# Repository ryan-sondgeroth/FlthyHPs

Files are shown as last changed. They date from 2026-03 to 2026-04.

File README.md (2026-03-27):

# FlthyHPs (Flthy Holoprojectors)

This repo contains the `FlthyHPs_v2.1.ino` sketch and supporting documentation for controlling 3 R2 holoprojectors (Front/Rear/Top) with:

- NeoPixel LED effects (7 LEDs per projector)
- Servo articulation through an Adafruit PCA9685 I2C board
- Auto-twitch behavior for both LEDs and servos
- Serial/I2C command control (plus optional RC input)

This README is based on the manual in [`docs/Guide to Using Your FlthyHPs v1.8 .docx`](docs/Guide%20to%20Using%20Your%20FlthyHPs%20v1.8%20.docx), with updates aligned to the current `v2.1` sketch.

## At a Glance

- **Sketch:** `FlthyHPs_v2.1.ino`
- **Arduino I2C address:** `0x19` (decimal 25)
- **PCA9685 I2C address:** `0x40` (default)
- **Serial baud:** `9600`
- **HP count:** 3 (Front, Rear, Top)

## Hardware

## PCB Renders

| Top | Isometric Front |
|-----|---|
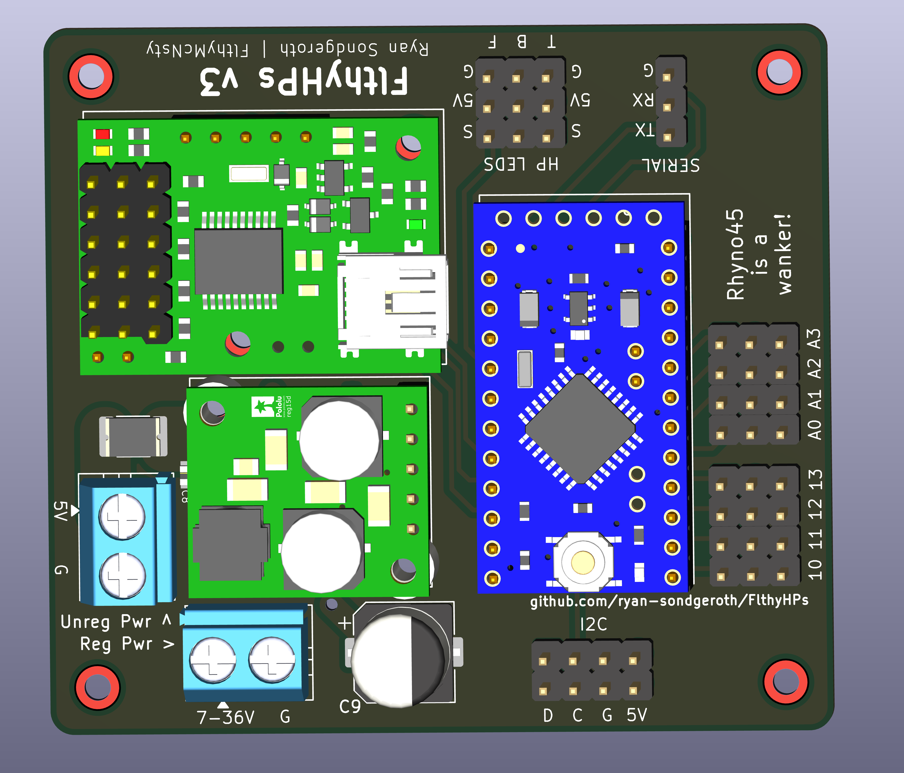
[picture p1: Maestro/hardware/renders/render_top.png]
Top view
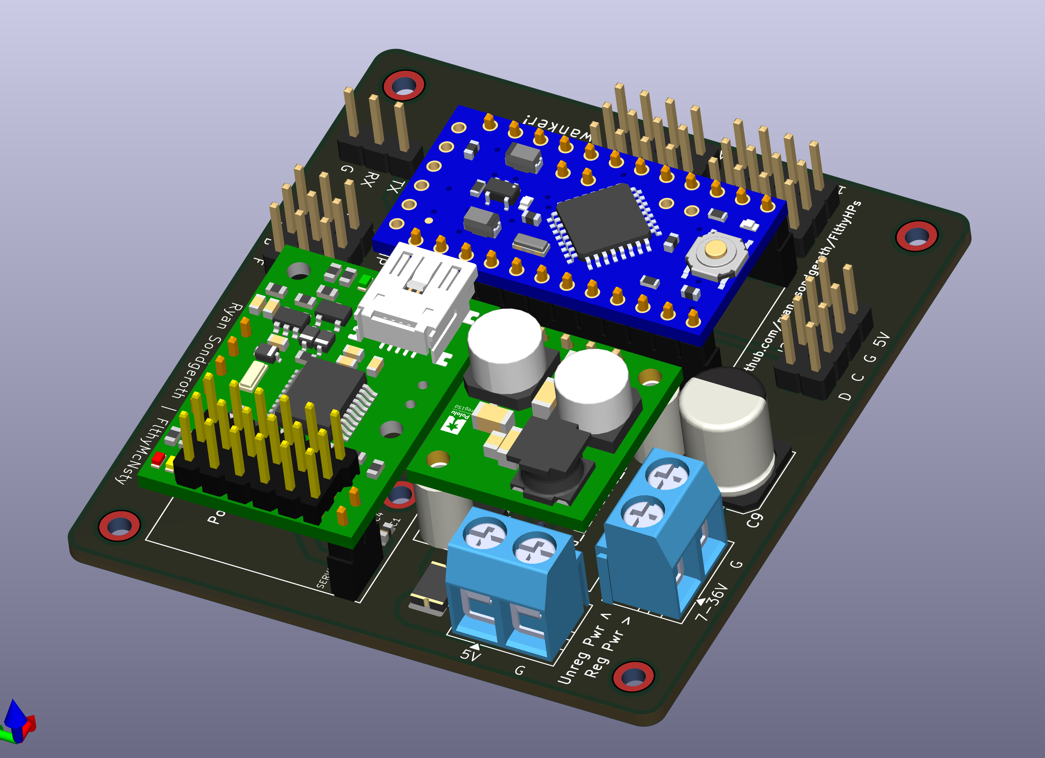
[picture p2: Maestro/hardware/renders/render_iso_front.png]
Isometric front
|  |  |

| Isometric Back | Side |
|---|---|
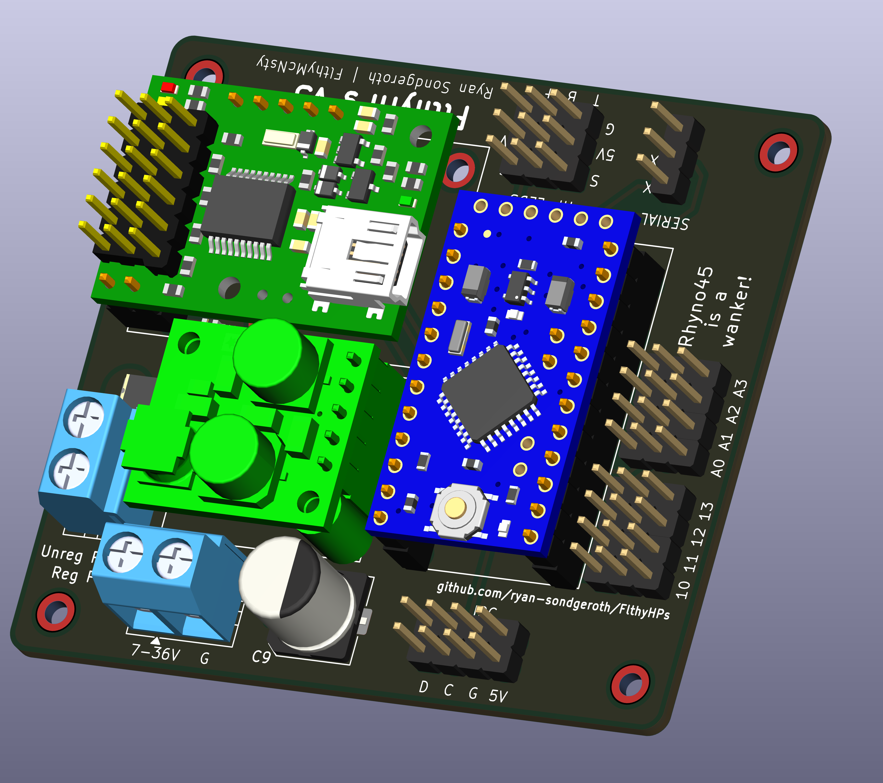
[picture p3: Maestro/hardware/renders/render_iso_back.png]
Isometric back
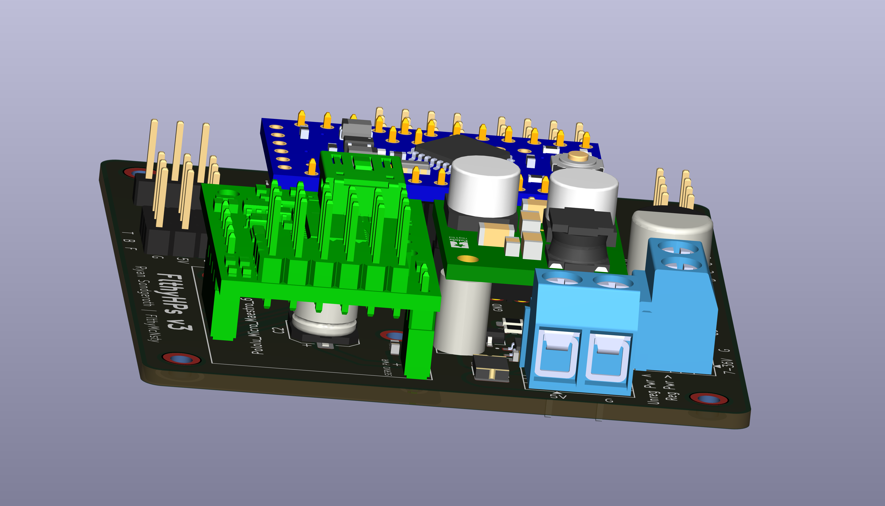
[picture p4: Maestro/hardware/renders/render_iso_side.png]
Side view
|  |  |

---

### FlthyHPs Maestro v3 PCB (current)

The v3 system replaces the separate breakout board + PCA9685 combo with a single custom PCB: **FilthyHPs_Maestro**.

- **Arduino Pro Mini** (5V, 16MHz) — plugs into U1 headers
- **Pololu Micro Maestro 6-Channel** servo controller — plugs into U2 headers (replaces PCA9685)
- **Pololu D24V50F5** 5V 5A regulator — plugs into U3 headers
- 6 servos (2 per HP) via Maestro channels 0–5
- 3 HP NeoPixel assemblies (7 LED Jewel each) via Arduino D2/D3/D4
- I2C headers (J6, J7) for external peripherals and accepting commands from I2C controllers
- Serial header (J2) for sending commands to the Arduino sketch

**Power input:**
- 7–36V unregulated via J1 screw terminal (regulated on-board by D24V50F5)
- Or regulated 5V direct via J8 screw terminal (bypasses regulator)

**Improved circuit protection over previous versions:**
- P-ch MOSFET (Q1) ideal diode gates VIN_RAW to the servo rail, preventing backfeed
- 5.1V Zener clamps (D1, D2) protect Maestro and Arduino signal lines from overvoltage
- 500mA PTC resettable fuse (F1) on the 5V logic rail — self-resetting, no fuse to replace

**Improved power stability over previous versions:**
- Bulk capacitance across the input, servo, and logic rails absorbs current spikes and smooths supply transients
- Decoupling capacitors at key IC supply pins suppress high-frequency noise

**Simplified servo setup over previous versions:**
- Moving to the Pololu Micro Maestro eliminates the tedious per-servo position configuration previously done in the sketch
- Servo travel limits, speeds, and positions are configured visually using the Maestro Control Center application, with no sketch changes required

Servo control and calibration: [`Maestro/Maestro_Setup_Guide.md`](Maestro/Maestro_Setup_Guide.md)

### Legacy hardware (v1/v2/v2.1)

Earlier versions used a Flthy breakout board + Adafruit PCA9685 servo driver. The v2.1 sketch still supports this hardware. See [`docs/README.md`](docs/README.md) for the full legacy wiring guide.

## Wiring (Default)

### Arduino pins (v3 Maestro PCB)

- `D2` Front HP LED data
- `D3` Rear HP LED data
- `D4` Top HP LED data
- `D9` RC input (optional, if enabled)
- `D10` Maestro `RST` (servo output enable control)
- `D13` status LED
- `A4/A5` I2C SDA/SCL (to J6/J7 I2C headers)
- `TX/RX` Serial to Maestro (via J2 Serial header)

### Maestro channels (v3)

- `0/1` Front HP servos
- `2/3` Rear HP servos
- `4/5` Top HP servos

### Legacy PCA9685 channels (v1/v2/v2.1)

- `0/1` Front HP servos
- `2/3` Rear HP servos
- `4/5` Top HP servos

## Required Libraries

- `Wire` (built-in)
- [Adafruit NeoPixel](https://github.com/adafruit/Adafruit_NeoPixel)
- [Adafruit PWM Servo Driver Library](https://github.com/adafruit/Adafruit-PWM-Servo-Driver-Library)
- Big Happy Dude Slow Servo library (`Servos.h`) vendored in this repo at `libraries/SlowServoPCA9685`

Note: the standard Arduino Servo library is not used due to NeoPixel timing conflicts.

### Vendored slow-servo library

This repo includes `libraries/SlowServoPCA9685` so the required `Servos.h` dependency is versioned with the sketch.

- Source in this repo: `libraries/SlowServoPCA9685`
- License in upstream headers: GNU GPL v3 or later
- Original copyright: Graham Short (2013)

## Setup and Flashing

1. Install Arduino IDE.
2. Install required libraries.
3. Install Adafruit libraries directly from upstream repos:

```bash
./scripts/install-adafruit-libs.sh
```

4. Install vendored slow-servo library from this repo:

```bash
./scripts/install-libs.sh
```

Optional: set `ARDUINO_LIB_DIR` if your Arduino libraries path is not `~/Documents/Arduino/libraries`.

5. Open `FlthyHPs_v2.1.ino`.
6. Set board to **Arduino Pro or Pro Mini** and select your FTDI serial port.
7. Adjust configuration values (if needed).
8. Upload and verify boot behavior.

## Key Sketch Settings

Common settings called out in the manual and present in the current sketch:

- `Config::I2C_ADDRESS` (`0x19`)
- `Config::SERVO_I2C_ADDRESS` (`0x40`)
- `OUTPUT_ENABLED_PIN` (`10`)
- `BRIGHTNESS` (`150`)
- `ENABLEBASICHP` (basic vs 9-point preset coordinate mode)
- `enableTwitchLED[]` and `enableTwitchHP[]`
- `LEDTwitchInterval[][]` and `HPTwitchInterval[][]`
- `SERVO_SPEED[]`
- `Config::ENABLE_SERVO_EASING` and easing duration/update interval (v2.1)

For RC control, enable the RC option in the sketch and confirm RC pulse range values match your radio.

## Command Model

Command format:

- `DT##`
- `DT##C`
- `DT##CS`
- `DT##P`
- Optional runtime suffix: `|seconds`

Where:

- `D` = device designator: `F`, `R`, `T`, `A`, `X`, `Y`, `Z`, or `S` (special sequence set)
- `T` = type: `0` LED, `1` servo
- `##` = 2-digit sequence ID
- `C` = color (0-9)
- `S` = speed (dim pulse speed 0-9)
- `P` = position (0-8 preset)

### Color values

- `0` random
- `1` red
- `2` yellow
- `3` green
- `4` cyan
- `5` blue
- `6` magenta
- `7` orange
- `8` purple
- `9` white

### LED sequences (Type `0`)

- `D001` Leia
- `D002C` Color projector
- `D003CS` Dim pulse
- `D004C` Cycle
- `D005C` Solid color
- `D006` Rainbow
- `D007C` Short circuit
- `D096` Clear LEDs, disable auto LED, disable off-color
- `D0971` Clear LEDs, auto LED default, disable off-color
- `D0972` Clear LEDs, auto LED random, disable off-color
- `D098` Clear LEDs, disable auto LED, enable off-color
- `D0991` Clear LEDs, auto LED default, enable off-color
- `D0992` Clear LEDs, auto LED random, enable off-color

### Servo sequences (Type `1`)

- `D101P` Go to preset position (`0..8`)
- `D102` RC control left/right
- `D103` RC control up/down
- `D104` Random position
- `D105` Wag left/right
- `D106` Wag up/down
- `D198` Disable auto servo twitch
- `D199` Enable auto servo twitch

### Special `S` sequences

- `S1` Leia mode (front down + Leia LEDs, others disabled)
- `S4` Clear + disable auto, off-color disabled
- `S5` Clear + enable auto (default LED twitch), off-color disabled
- `S6` Clear + enable auto (random LED twitch), off-color disabled
- `S7` Clear + disable auto, off-color enabled
- `S8` Clear + enable auto (default LED twitch), off-color enabled
- `S9` Clear + enable auto (random LED twitch), off-color enabled

### Timed command examples

```text
A006|25     # Rainbow on all HPs for 25s
F001|60     # Leia on Front HP for 60s
T1012|10    # Move Top HP to preset 2 for 10s
```

## MarcDuino Integration (from manual)

The manual includes MarcDuino `v1.5/v2` usage over I2C. Core idea:

- Connect SDA/SCL/GND between MarcDuino and FlthyHPs controller.
- Send a string command to FlthyHPs address (`25` decimal by default).
- Example:

```text
&25,"A006|10\r
```

If another device already uses address `25`, change `Config::I2C_ADDRESS` in the sketch and update MarcDuino command address accordingly.

## Notes

- The manual in `docs/` is `v1.8`; this repo sketch is `v2.1`.
- If details conflict, treat `FlthyHPs_v2.1.ino` as source of truth.

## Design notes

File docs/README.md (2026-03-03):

# Guide to Using Your FlthyHPs
by Ryan Sondgeroth
flthymcnsty

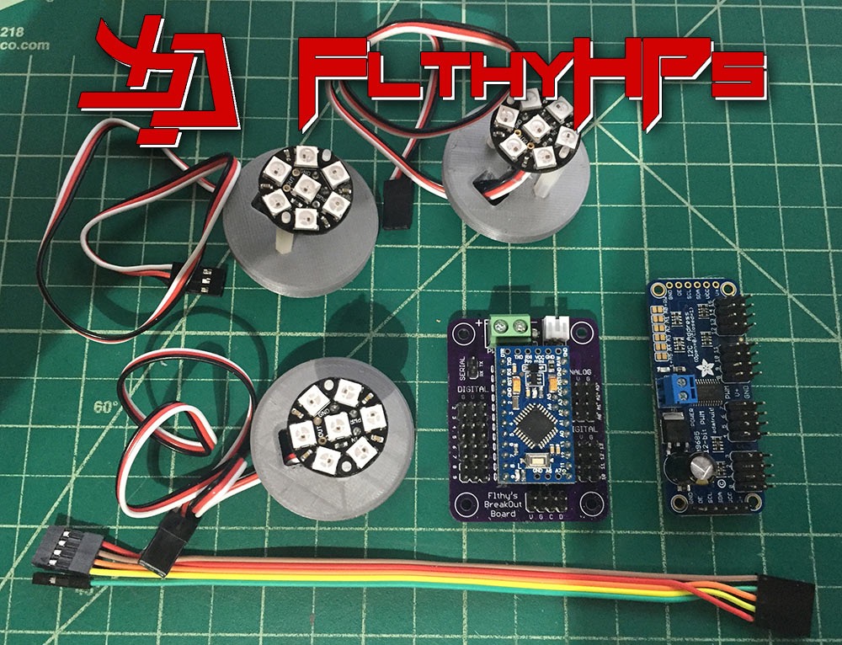
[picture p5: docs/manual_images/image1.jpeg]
Manual image 1


## Table of Contents
- What are the FlthyHPs
- What’s in the Kit
- Hooking Up Your HPs v1
- Hooking Up Your HPs v2
- Hooking Up Your HPs v2.1
- Understanding the Sketch Settings
- 1. I2C Address of the System
- 2. I2C Address of the Servo Board
- 3. HP LED Pin Assignment
- 4. Servo Board Pin Assignment
- 5. Output Enabled (OE) Pin Assignment
- 6. Enable/Disable OE
- 7. RC Enable & Input Pin Assignment
- 8. RC Pulse Width Range
- 9. Adafruit Jewel Board Version
- 10. LED Brightness
- 11. Enable/Disable LED Auto Twitch
- 12. Default LED Auto Twitch Commands
- 13. Enable/Disable Servo Auto Twitch
- 14. LED & Servo Auto Twitch Interval Ranges
- 15. Servo Speed Range
- 16. Preset HP Servo Position Coordinates
- 17. Default Color Settings
- 18. Optional Default “Off” Color
- 19. Dim Pulse Speed Range and Default Speed
- I2C/Serial Command Structure
- Special Sequence Commands
- Replacement Back Plug
- Finding Your Preset Servo Position Coordinates
- Build it Yourself
- How to Update & Flash Sketch on Arduino Pro Mini
- Using the FlthyHPs with your Marcduino v1.5/v2

## What are the FlthyHPs
What do they do and Why you want a set!
This system and sketch combines the movement and display functions of each Holoprojector into a single easy to control sketch.  Instead of using a single RGB like other HP systems, the FlthyHPs utilizes a 7 LED NeoPixel board inside each HP to produce a more life-like representation of a hologram projection.
Servo control of the system is handled by a Adafruit 16 Channel I2C Breakout board, giving increased flexibility over the I2C bus while providing significant current to safely run your HP servos.
This system also allows us to operate the HP Servos with NeoPixel LEDs from the same sketch, a problematic solutions when attempting to use the stock Arduino servo library with Adafruit’s NeoPixel library.  Big Happy Dude's Slow Servo Library is much better any way, Thanks Brad!
The system incorporates semi randomized auto twitch sequences for both the LEDs and Servos of each HP giving your droid the illusion of autonomy.   In addition to these free running auto modes,  the LED and Servo behavior can be controlled in unison or separately through a variety of sequences triggered via I2C and Serial  communication protocols.   To simplify control,  the FlthyHP system allows you to control HP functionality by sending all HP commands to a single device.
The most current version of this manual can be found at:
<http://2gwd.com/FlthyHPs/Manual/>
Rhyno45 is a Wanker, in case Ya'll didn't know!

## What’s in the Kit
Below is a picture of the complete contents of your HP kit.  Please make sure everything is included before you begin. A brief description of each part/assembly is included below.
Each system comes pretested and pre-installed with the current sketch and default settings.

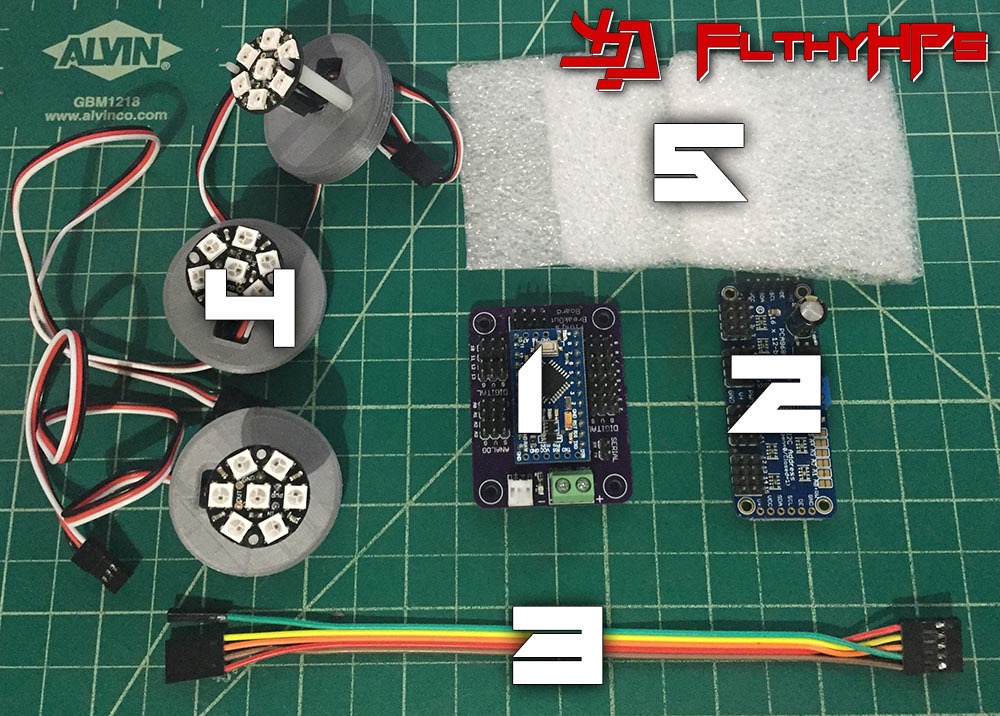
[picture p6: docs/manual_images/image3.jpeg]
Manual image 2


### 1. Arduino Pro Mini (5v 16MHz) on a Flthy Breakout Board.
The Flthy Breakout Board is a custom designed PCB* which conveniently breaks out the digital and analog pins of the Arduino Pro Mini into easy-to-use connections.   It also breaks out the Serial Tx/Rx and I2C Clock/Data pins.
The boards include a screw terminal for connecting your 5v power.  The newer v2 & v2.1 boards also break out a header row specifically for connecting to the Servo breakout board discussed below in item 2.
There have been three versions of this board, with v2.1 incorporating slight design improvements.  Sketches work on either board version.
*The breakout board designs are based on the publicly CAD Eagle files available on letsmakerobots.com.

Original Board (v1)

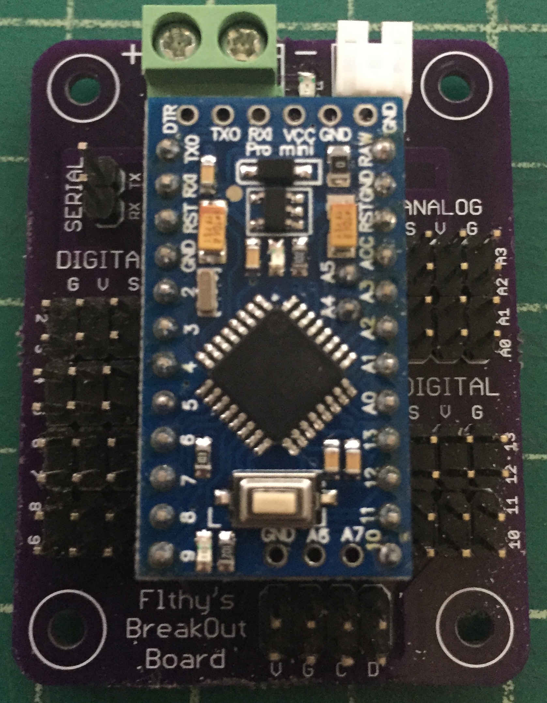
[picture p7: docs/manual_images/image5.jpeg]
Manual image 3


v2 Board 

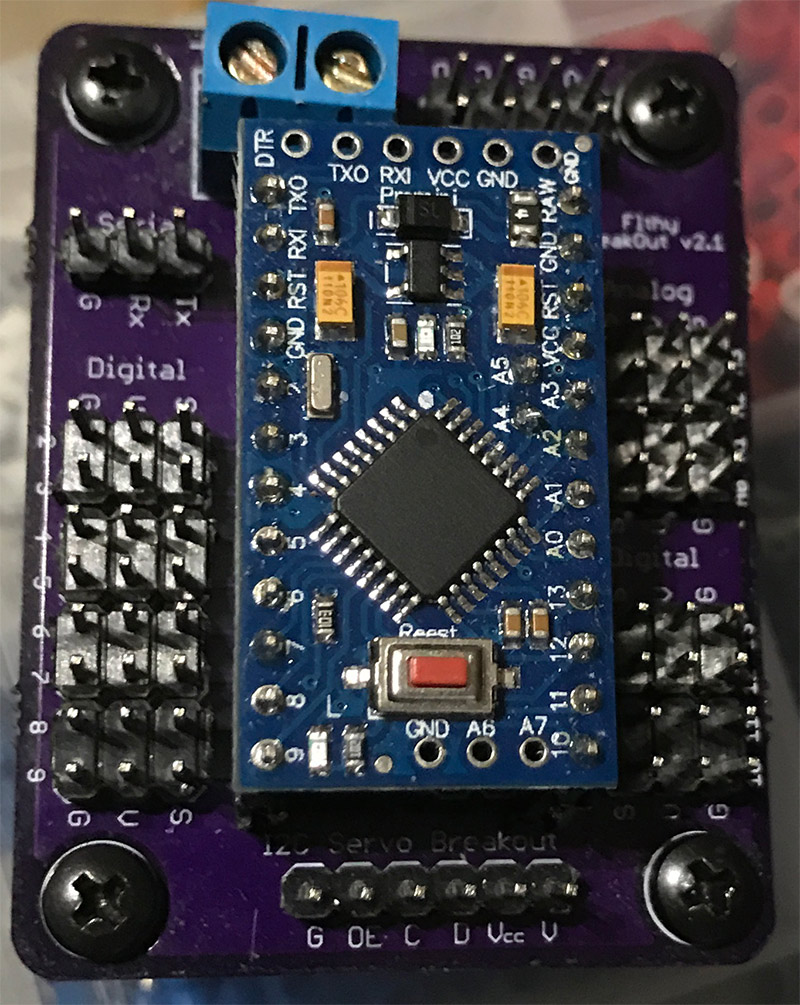
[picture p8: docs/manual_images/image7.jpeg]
Manual image 4


v2.1 Board

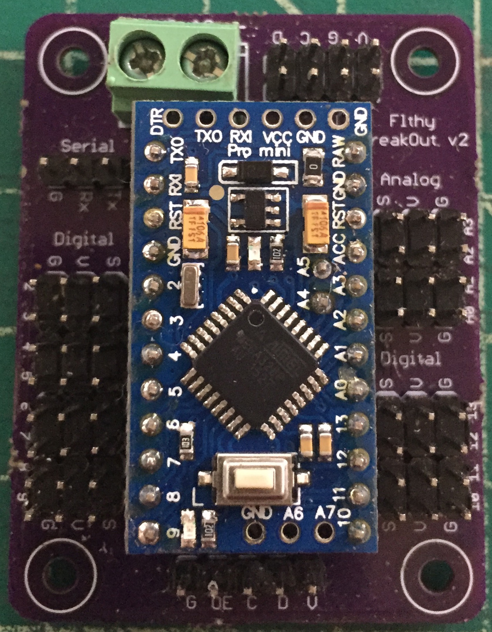
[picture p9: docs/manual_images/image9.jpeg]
Manual image 5


*The v2.1 breakout board incorporates a few design improvements making connections to it much easier.

### 2. Adafruit 16 Channel I2C Servo Breakout board*

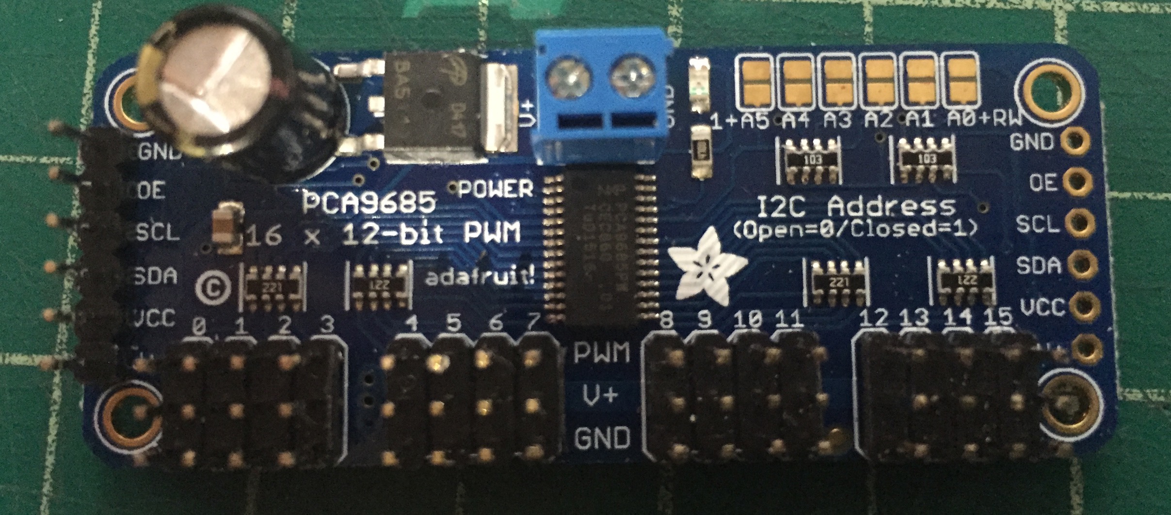
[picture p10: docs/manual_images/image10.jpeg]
Manual image 6


See product info at
<https://www.adafruit.com/product/815>
*Optional…Because some R2 Builders may not wish to articulate their HPs, some kits are available without this board.

### 3. 6 Wire Jumper Cable
For kits using the newer v2.1 Break Out Board, this is simply a basic straight 6 wire jumper cable as the header pins are broken out in the same arrangement as they appear on the Servo board including the V line.   This was done to simplify the connection process.
For kits using the v2 Break Out Board, this is simply a basic straight 5 wire jumper cable as the header pins are broken out in the same arrangement as they appear on the Servo board minus the V line.   This was done to simplify the connection process.
For kits using the v1 Breakout Board, a pre-wired jumper cable is used to connect the Servo Breakout Board to the Arduino.   It has the wires swapped correctly for proper connection.

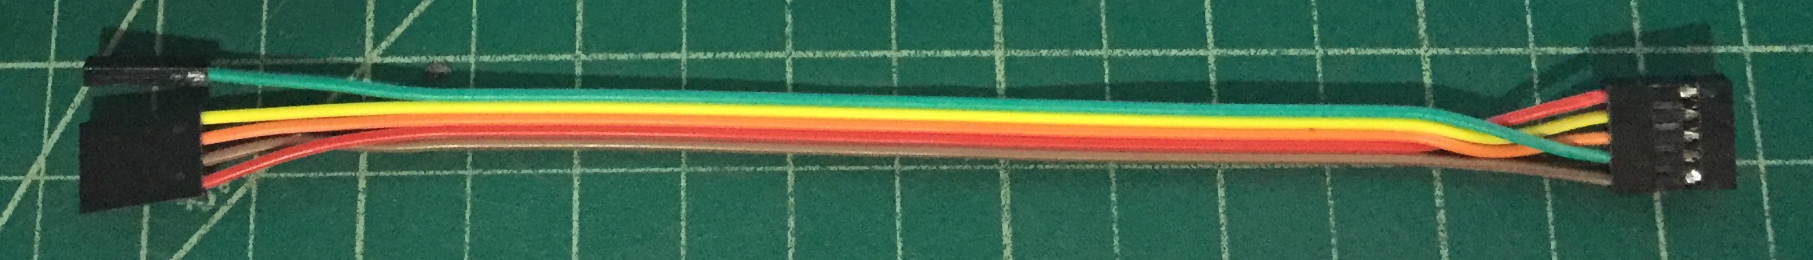
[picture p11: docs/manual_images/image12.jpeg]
Manual image 7


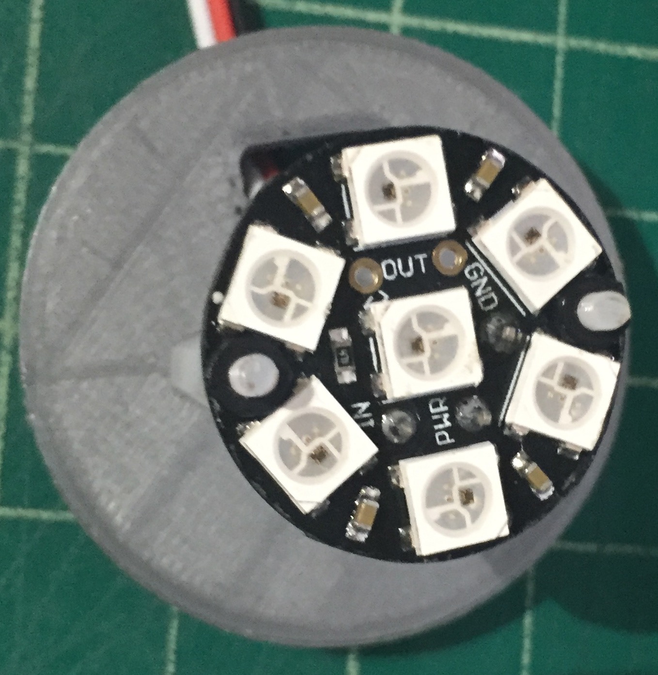
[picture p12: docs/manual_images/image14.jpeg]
Manual image 8


### 4. HP LED Assemblies (Qty. 3)
Each assembly consists of a Adafruit NeoPixel Jewel 7 LED Board (https://www.adafruit.com/products/2226), mounted on a custom 3D printed backplate via M2 nylon standoffs and connected with a 30cm 3 wire lead.
There are now 3D printed back plates available for the recent Pwrsrce (1 5/8”-20 threads) aluminum halo-projector run as well as those for the BobC HPs (1 5/8”-24 threads).
The center hole comes tapped for an M4 patterned bolt.

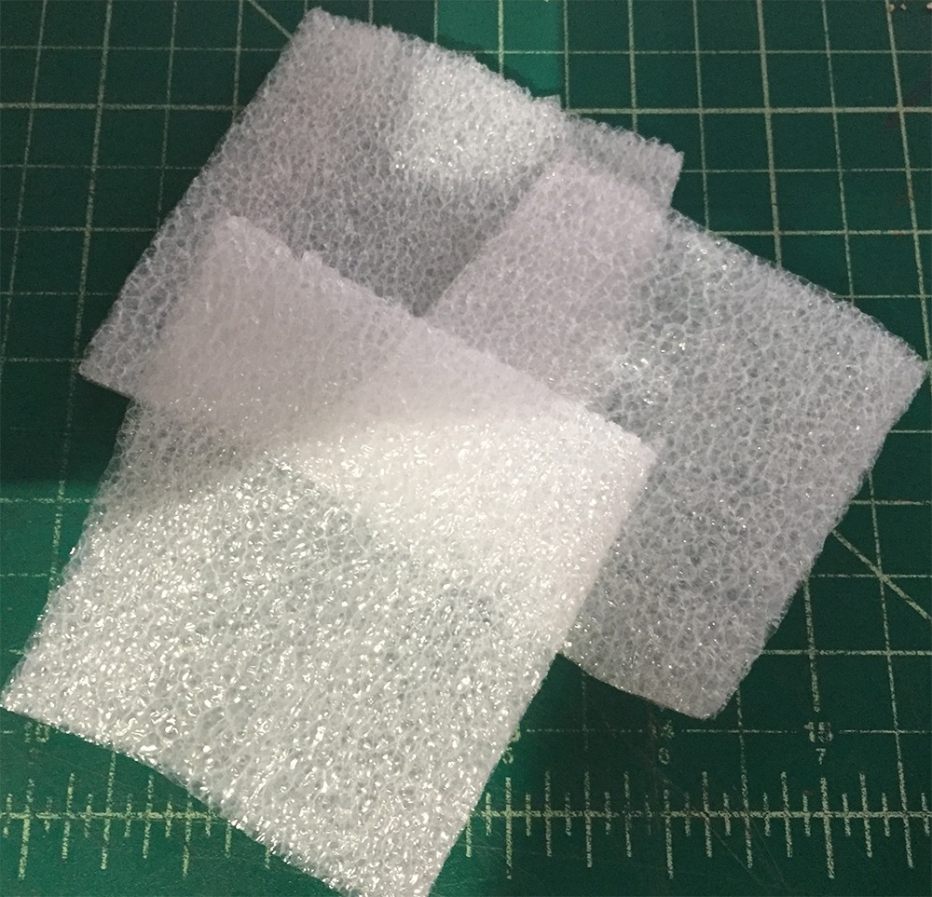
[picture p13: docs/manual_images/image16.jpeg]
Manual image 9


### 5. 1/4" Micro Foam Packaging Wrap (Qty. 3)
These 3 pieces can serve as a light diffuser between the HP’s LEDs and its lens, just cut to size.  They help blur the lines between the individual LEDs while maintaining a multicolor display.  The foam construction also gives the HP’s light a unique texture when looking directly into the lens. (Which I don’t recommend you do for long periods of time)

## Hooking Up Your HPs v1
What Wires Go Where?
Wiring Diagram for kits with Original v1 Breakout Boards
The wiring for this system is straight forward.  Both boards take 5v with the servos and LEDs attached as shown.

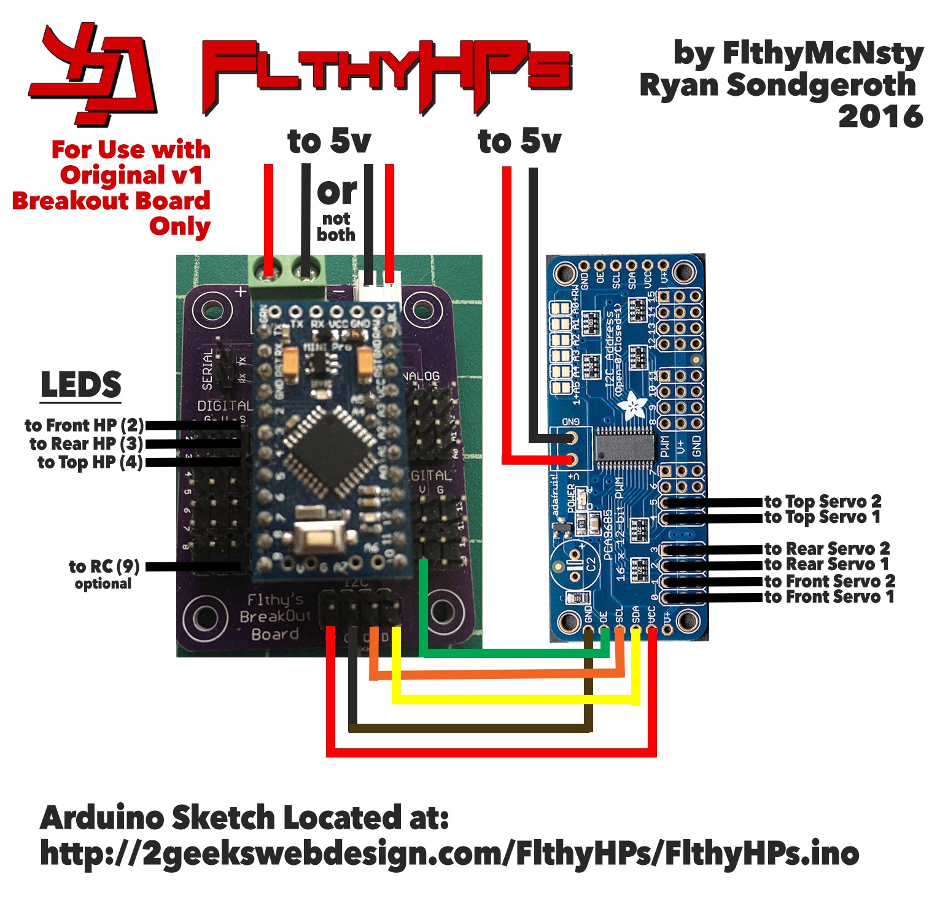
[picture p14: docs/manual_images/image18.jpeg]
Manual image 10


Attention for Kits Using the Original v1 Breakout Board!
Pay special attention to the wiring between the v1 Arduino breakout board and the servo breakout board.  The servo breakout board uses a different pin layout than the standardized I2C pin layout used by other systems created by R2 Builders.  Incorrectly connecting the servo board can result in damage.  In order to help prevent this occurrence, each kit is provided with a 5 wire jumper cable (pictured below) which has been rearranged into the correct wiring pattern with each wire matching the color used in the wiring diagram above.
Custom Wire for the Original v1 Board Design

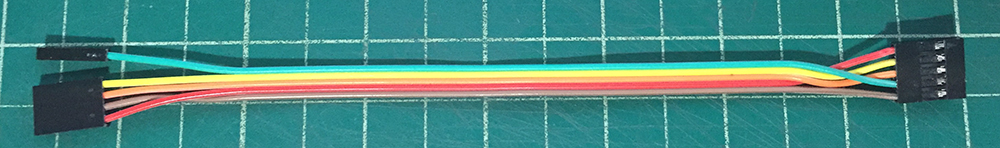
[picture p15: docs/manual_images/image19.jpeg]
Manual image 11


The v2 breakout board breaks out the pins in the same order as the servo board, simplifying the connection, and minimizing the confusing wiring.

## Hooking Up Your HPs v2
What Wires Go Where?
Wiring Diagram for kits with v2 Breakout Boards
The wiring for this system is pretty straight forward.  Both boards take 5v with the  servos and LEDs attached as shown.

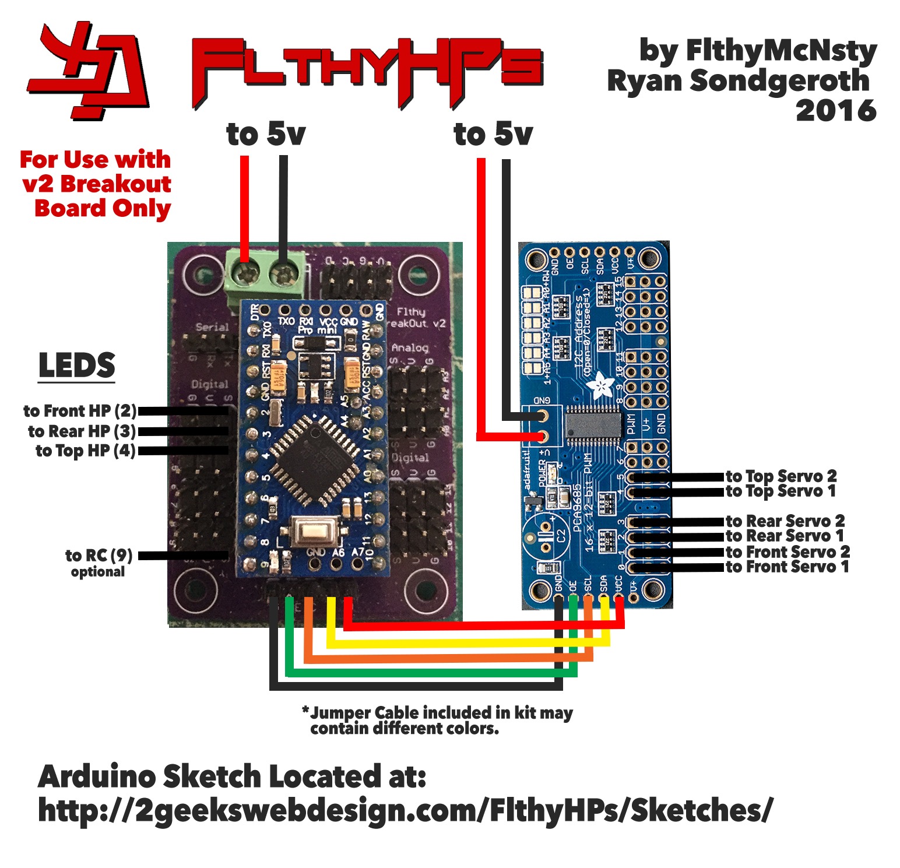
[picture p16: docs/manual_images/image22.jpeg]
Manual image 12


## Hooking Up Your HPs v2.1
What Wires Go Where?
Wiring Diagram for kits with v2.1 Breakout Boards
The wiring for this system is straight forward.  Both boards take 5v with the servos and LEDs attached as shown but the v2.1 now includes a V pin on the Servo Board Pin Out, so you do not need to provide separate power to the I2C servo breakout board.

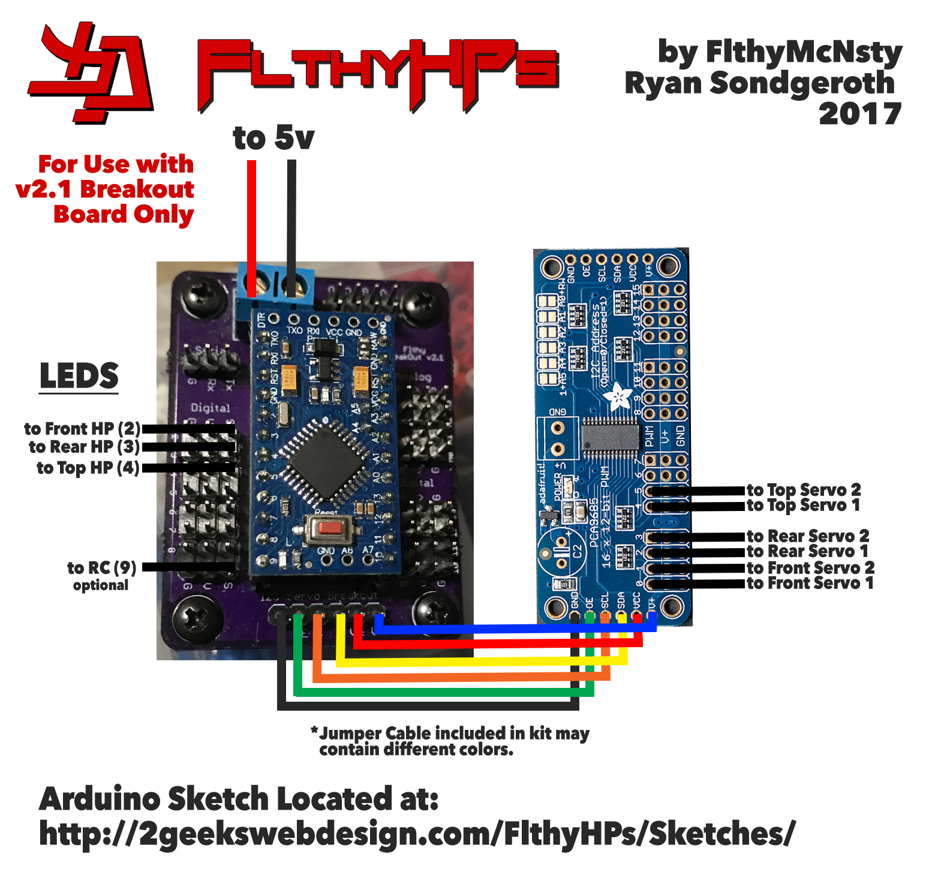
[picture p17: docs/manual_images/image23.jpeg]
Manual image 13


## Understanding the Sketch Settings
Explanation of User Definable Settings in the v2.1 Code (v1.8-compatible with v2.1 additions)
I keep the most current versions of my FlthyHP sketch freely available on my web server at: http://2gwd.com/FlthyHPs/Sketches
For those who use my sketch and feel you may have a way to improve upon it, please share your ideas and thoughts with me.   Together we can continue to improve our droids.
As you review the sketch, you will see I have broken out several settings into user definable variables in order to let each user tweak the system to their specific needs.  Below is a complete list of each of these variables with a brief explanation of its function and purpose.

### 1. I2C Address of the System
Since each device on the I2C bus can and must be assigned its own unique address, this variable allows you to do so.  An I2C address of 25 has been standardized for other HP devices so I used it as well.   It can be changed with the following variable.   Please note that it is set using the hexadecimal equivalent of the address’s decimal value.
```cpp
constexpr uint8_t I2C_ADDRESS = 0x19;  // 25 in hexadecimal
```

### 2. I2C Address of the Servo Board
Similarly, we need to set a unique I2C address for the Adafruit Servo Breakout Board.
Unlike our Arduino based control board, the Servo Breakout board is only capable of using an I2C address in the range between 64 and 126.   The specific address the board uses can be set using the set of 6 solder pads located on the top of the PCB.  By default, the board has an address of 64, and no changes are needed if you are not using the same board elsewhere on the I2C bus or have assigned another device with this address.

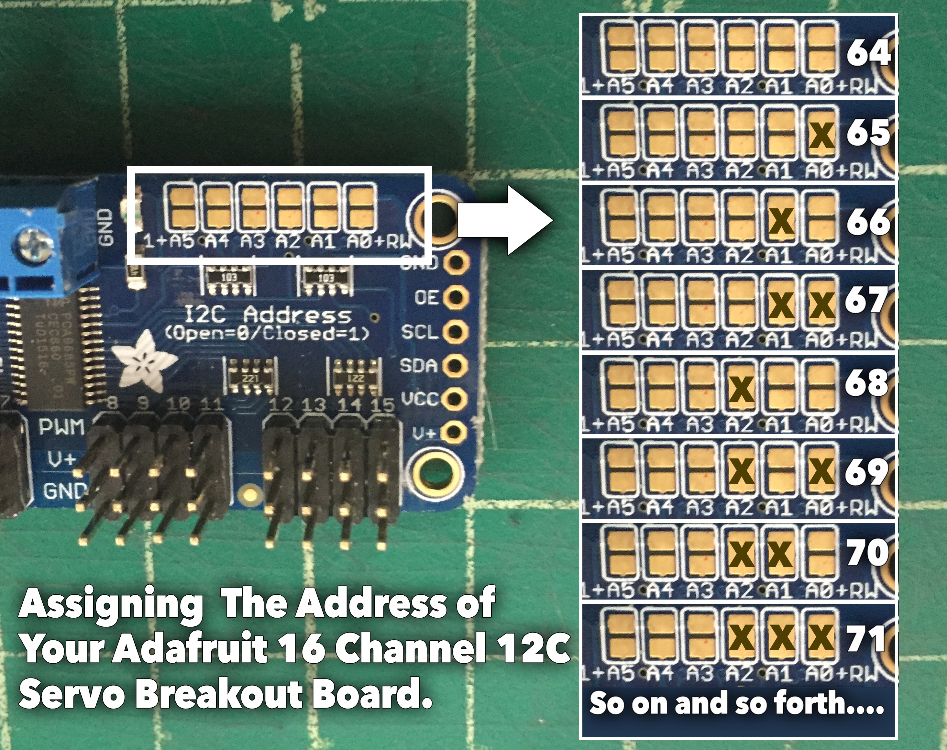
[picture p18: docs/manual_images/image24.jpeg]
Manual image 14


However, if you do need to make changes to the boards address you can do so by using the solder pads to select a new address value.  To do so, you simply place a bead of soldier across the gap in the requisite pad pairs.
The address value is determined just as you would using binary as show in this image.
Once you have set your Servo board’s address, you will then need to change this address in the Sketch.  It can be changed with the following variable.   Again, please note that it is set using the hexadecimal equivalent of the address’s decimal value.
```cpp
constexpr uint8_t SERVO_I2C_ADDRESS = 0x40;  // 64 in hexadecimal
```
If there is no need to reassign the Servo board’s address, the default value in the sketch can be left as is.

### 3. HP LED Pin Assignment
This variable allows you to set which of the Arduino’s digital pins are used to connect each of the 3 LED displays.  The first value being the front HP, the second the rear HP and the third the top HP.   Under most situations, the default values can be left unchanged.
```cpp
const uint8_t LED_PINS[Config::HP_COUNT] PROGMEM = {2, 3, 4};  // {Front, Rear, Top}
```

### 4. Servo Board Pin Assignment
This variable allows you to set which of the Servo breakout board’s pins are used to connect each of the 6 servos.  The first value pair being for the front HP, the second value pair for the rear HP and the third pair for the top HP.   Under most situations, the default values can be left unchanged.
```cpp
// Front HP Pins, Rear HP Pins, Top HP Pins
const uint8_t HP_PINS[Config::HP_COUNT][2] PROGMEM = {{0,1}, {2,3}, {4,5}};
```
Important: It is recommended that you remain consistent with how you orient your HP mounts and control system so that the two servos for each HP are positioned in a similar manner with the others.  Likewise, pin assignments/servo connection should be consistent as well between the HPs.  This will help keep their behavior during movements consistent.

### 5. Output Enable (OE) Pin Assignment
The servo breakout board is equipped with Output Enabled (OE) capabilities.  Output Enable is used to disable/enable power to the servos between movements by pulling the OE pin on the servo break outboard to LOW.   This is used to minimize the unnecessary and unwanted hum/noise often heard when a servo fails to reach its exact destination after a movement command is executed.  Under most situations, the default value can be left unchanged.
```cpp
#define OUTPUT_ENABLED_PIN 10
```

### 6. Enable/Disable OE
In some rare cases* you may wish to not use the Output Enable capabilities.  You can disable OE by setting the following variable to 0.
```cpp
#define OUTPUT_ENABLED_ON true
```
* The only reasons you would want to disable this is if…
You wish to use an additional micro-controller to send servo control commands via the Adafruit library.
You want to use additional servos on the same servo breakout board as your HP servos.
Neither scenario is recommended because the increased complexity it introduces far outweighs the costs savings of not purchasing an additional servo board.

### 7. RC Enable & Input Pin Assignment
If you plan on using the RC functions to control your HPs, uncomment the following line.  Otherwise, leaving it commented as it out frees up some system resources.
```cpp
//#define ENABLERC
```
This variable allows you to set the digital pin used to feed a single RC input into the system to be read when the system’s RC function has been triggered via Serial or I2C command.  The RC function allows you to move a selected HP up or down using one of your controllers’ sticks.   Currently the system only supports movement on a single axis, and its use is completely optional.  Under most situations, the default values can be left unchanged.
```cpp
constexpr uint8_t RC_PIN = 9;  // active only when ENABLERC is enabled
```

### 8. RC Pulse Width Range
Since RC controllers/PWM sources are different, this variable allows you to set a min and max pulse width value to map to the end positions of the up/down axis of movement.   Which value corresponds with up and which corresponds with down is dependent on your specific set up so you may need to switch the order of the two values.
```cpp
const uint16_t RC_RANGE[2] PROGMEM = {1250, 1750};     // {Min, Max}
```

### 9. Adafruit Jewel Board Version
The Adafruit Jewels now come in RGB and RGBW versions, uncomment the following if you have the RGBW version.
```cpp
//#define NEO_JEWEL_RGBW
```

### 10. LED Brightness
If you need to adjust the brightness of your LEDs, simply change the value of the following variable.  It accepts a range from 0-255.   The higher the brightness, the more power the system requires.
```cpp
constexpr uint8_t BRIGHTNESS = 150
```

### 11. Enable/Disable LED Auto Twitch
Each HP can be set independently from each other to twitch its LEDs automatically at various intervals to give your droid a sense of autonomy. This auto twitch behavior can be enabled/disabled using the following variables.   Auto Disable = 0, Auto Enabled w/ Default Sequence = 1, Auto Enabled w/ Random Sequences = 2
```cpp
byte enableTwitchLED[HPCOUNT]  = {1,1,1};              // Leds:   Front, Rear, Top
```

### 12. Default LED Auto Twitch Commands
This setting allows you to assign the default twitch sequence behavior for each HP utilizing command stricture strings.
```cpp
const byte defaultLEDTwitchCommand[3][3] = {{1,5,0},    // FRONT HP: Sequence, Color, Speed
{1,5,0},    // REAR HP: Sequence, Color, Speed
{1,5,0}};   // TOP HP: Sequence, Color, Speed ;
```

### 13. Enable/Disable Servo Auto Twitch
Each HP can be set independently from each other to twitch its servos automatically at various intervals to give your droid a sense of autonomy.  Furthermore, the servos of a single HP can be set to twitch independently from each other as well.   This auto twitch behavior can be enabled/disabled using the following variables.   Enabled = true, Disabled = false
```cpp
boolean enableTwitchHP[HPCOUNT] = {true,true,true};  // Servos: Front, Rear, Top
```

### 14. LED & Servo Auto Twitch Interval Ranges
The length between twitches can be adjusted by using these values to select the range (min, max) in seconds to randomly select the next auto twitch interval.  This helps give the illusion these displays & movements are totally autonomous as the interval between the same HP twitching will randomly change each time.  First value is the min, and the second value is the max time in seconds.
```cpp
const unsigned int LEDTwitchInterval[HPCOUNT][2] = {{240,360},        //Enter min & max seconds, Front LED                                                             						           {300,420},     //Enter min & max seconds, Rear LED
{300,420}};   //Enter min & max seconds, Top LED
const unsigned int HPTwitchInterval[HPCOUNT][2] = {{45,120},     //Enter min & max seconds, Front Servos
{60,180},     //Enter min & max seconds, Rear Servos
{60,180}};    //Enter min & max seconds, Top Servos
```
Since R2-D2 is seen in the films to move his HPs often yet rarely projects from them, the default settings have the servo twitch occurring more often than the LED twitch.15. LED & Servo Auto Twitch Runtime Ranges
In addition to the interval between LED twitches, you can also set the duration the LEDs remain illuminated when executed.  This too helps give the illusion these displays are totally autonomous as they operate for a different length of time each time a twitch is executed. First value is the min, and the second value is the max time in seconds.
```cpp
const unsigned int LEDTwitchRunInterval[HPCOUNT][2] = {{5,25},    // (5-25s) Front LED Runtime
{5,25},    // (5-25s) Rear LED Runtime
{5,25}};   // (5-25s) Top LED Runtime
```

### 15. Servo Speed Range
The servo speed range can be set setting the min and max speed settings via the variable below.  Values are in ms with lower values resulting in faster servo movement.  By using a range, the servos will not always move at the same speed giving the subtle illusion that each movement is purposeful and unique.
```cpp
const int SERVO_SPEED[2] = {150, 400};
```

### 16. Preset HP Servo Position Coordinates
The following settings can be confusing, so I made every effort here to explain them at length.
Since each Builder's droid is assembled differently, we found using position coordinates generated randomly on the fly was   problematic due to the occasional servo movement attempting   to travel beyond the outer cowl path.  Therefore, we use a set of 9 position pairs for each HP, set to ensure they lie with in a freely accessible position. These coordinates consist of the servo position of each servo using its pulse width value in microseconds. I suggest using a servo tester with   a digital display to find these position pairs while the HPs are mounted in the dome.
The first coordinate pair in each row references the DOWN position of the HP, the second pair is the CENTER position, and the 3rd pair the UP position.  LEFT, UPPER LEFT & LOWER LEFT are plotted using the fourth, fifth and sixth pairs while RIGHT, UPPER RIGHT & LOWER RIGHT are plotted using the seventh, eighth and ninth pairs
Random twitch movement is then chosen to randomly travel between these 9 safe points minimizing the chance of the movement being impeded causing excessive and unpleasant servo noise.
Important: The following values are unique to my HP Control setup and are only used as place holders.  They will not work as intended in your set up without first finding your own position values and entering
them below.  Likewise, your values will not work in other builders set up.   There are simply too many variables involved in how HPs are mounted to create a global set of positions that work between droids.
```cpp
const PROGMEM uint16_t  HPpos[HPCOUNT][HPPOSITIONS][2] = {{{1377,1706},   // Front HP Down
{1477,1426},   // Front HP Center
{1422,1161},   // Front HP Up
{1611,1425},   // Front HP Left
{1611,1155},   // Front HP Upper Left
{1611,1739},   // Front HP Lower Left
{1255,1434},   // Front HP Right
{1255,1115},   // Front HP Upper Right
{1255,1729}},  // Front HP Lower Right
{{1582,1330},   // Rear HP Down
{1500,1512},   // Rear HP Center
{1466,1773},   // Rear HP Up
{1705,1598},   // Rear HP Left
{1705,1797},   // Rear HP Upper Left
{1705,1389},   // Rear HP Lower Left
{1286,1460},   // Rear HP Right
{1286,1602},   // Rear HP Upper Right
{1285,1283}},  // Rear HP Lower Right
{{1507,1208},   // Top HP Down
{1501,1467},   // Top HP Center
{1443,1680},   // Top HP Up
{1624,1468},   // Top HP Left
{1624,1667},   // Top HP Upper Left
{1653,1272},   // Top HP Lower Left
{1267,1468},   // Top HP Right
{1258,1756},   // Top HP Upper Right
{1395,1176}}}; // Top HP Lower right
```
Basic Positioning*:
If you would rather do things the simple way, you can set the Basic Position mode below.  This will use the Center, Min and Max pulse width values set in the HPposBasic array. These are based on the assumed default center value of a normal servo, so it is important that your servo linkage is installed in a manner where the center servo position corresponds with the orientation you want your HP to be at when centered.
```cpp
#define ENABLEBASICHP true      // Comment line out to  disabled
const PROGMEM uint16_t HPposBasic[2][3] = {{1500,1300,1700},        // HP Servo 1 Values for Basic Mode (Center, Min, Max)
{1500,1300,1700}};       // HP Servo 2 Values for Basic Mode (Center, Min, Max)
```
enabled by default on new kits to increase their plug and playability.
Important: If you disassemble your HPs and servo linkage after setting custom Pre-Set values or custom Basic Position values, you will most likely need to recheck and reset them as the chances of reinstalling them the same way is approximately 3,720 to 1.
I also suggest once you measure your position values, you maintain a backup list of those values separate from your saved sketch.   There is a couple of reasons for this, the most important being in the event you need to reinstall the default sketch, or I release an updated version you wish to use, this backup list will keep you from needing to measure your position values again.  No one likes to have to mess with dome wiring after it has been neatly ran.
RC mode requires preset position coordinates to work well, so you must have enableBasicHP set to 0 and the HPpos array set with your specific values.

### 17. Default Color Settings
These settings allow you to set the default colors for the Auto Twitch/Leia and Short Circuit Sequences respectively.   Currently, there is a choice of 8 basic colors you can use when setting these defaults.
Basic Color Integer Values
1 = Red
2 = Yellow
3 = Green
4 = Cyan (Aqua)
5 = Blue
6 = Magenta
7 = Orange
8 = Purple
9= White
0 = Random
Simply use the integer value from the color list above in each of the default color variables below for each HP.
```cpp
const uint8_t defaultColor[HPCOUNT] = {5,5,5};      // {Front, Rear , Top} Color value for default sequence.
const uint8_t shortColor[HPCOUNT] = {7,7,7};        // {Front, Rear , Top} Color value for Short Circuit Sequence
```
The few times we see R2-D2 use his projector in the films, the Holograms projected had a blue tint to them, we selected blue as the default color to closely resemble this behavior.   We also chose it because MKelly and Ripcord were whiney little girls about it. :-)

### 18. Optional Default "Off" Color
The default state of the LEDs is unlit, i.e. Black.  If you would rather have the “off” state be a static color, so each HP remains a static color between twitches and sequences, set the color integer value from the table listed in the Default Color Settings comment for the corresponding HP.  Use the value -1 for off.  You will see this color after initial twitch if set.
```cpp
const int offcolor[HPCOUNT] = {-1,-1,-1};      // {Front, Rear , Top}   Off (Default) = -1
```

### 19. Dim Pulse Speed Range and Default Speed
Use this variable to set the default speed of the Dim Pulse function.
```cpp
constexpr uint8_t DIM_PULSE_SPEED = 5;  // Default speed if no value is supplied
const uint8_t DIM_PULSE_SPEED_RANGE[2] PROGMEM = {5, 75};  // Lower values are faster.
```

## I2C/Serial Command Structure
How to Make Your HPs Do Some Unique Things

### Command Structure
Most of the commands available to to you over I2C or Serial communication come in the form of a 4–5-character alphanumeric string .  This string uses a well defined composition utilizing the following structure:
DT##C or  DT##CS  or  DT##P  or DT## or DT###
D - the HP designator; used to select the specific HP you wish to send the command to.
Value Options:   F - Front HP, X - Front & Rear HPs
R - Rear HP, Y - Front & Top HPs
T - Top HP, Z - Rear & Top HPs
A - All 3 HPs, S - Special Sequence Commands
T - the Sequence Type;
Value Options:  0 - LED Function
1- Servo Function
## - the Sequence Value (including leading zero);
LED Sequences
Value Options:  01   - Leia Sequence, Random shades of blue to mimic Leia Hologram*
02   - Color Projector Sequence, Like Leia above using color command value
03   - Dim Pulse Sequence, Color slowly pulses on and off  (color & speed options)
04   - Cycle Sequence, using color command value                                          			                                                            		               05   - Toggles Color, simply sets LEDs to solid color value.
06   - Rainbow Sequence*
07   - Short Circuit, LED flashes on and off with interval slowing over time
96   - Clears LED, disables “Off Color”, Disables Auto LED Sequence*
0971 (D0971) - Clears LED, disables “Off Color”, Enables Auto LED Sequence using Default Sequences*
0972 (D0972) - Clears LED, disables “Off Color”, Enables Auto LED Sequence using Random Sequences*
098  (D098)  - Clears LED, enables “Off Color”, Disables Auto LED Sequence*
0991 (D0991) - Clears LED, enables “Off Color”, Enables Auto LED Sequence using Default Sequences*
0992 (D0992) - Clears LED, enables “Off Color”, Enables Auto LED Sequence using Random Sequences*
* Color Value Below Unneeded, Therefore Ignored, Can Be Omitted From Command String
Servo Sequences
Value Options:  01 - Sends HP to a Preset Position (requires position value)*
02 - Enables RC Control on HP (Left/Right)*
03 - Enables RC Control on HP (Up/Down)*
04 - Sends HP to a Random Position
05 - Wags HP Left/Right*
06 - Wags HP Up/Down*                                       			                  			 	                                     98 - Disables Auto HP Twitch
99 - Enables Auto HP Twitch
*Function disabled or severely limited when Basic HP Positioning in enabled.
C - Color Value from the list below:
Value Options:  1 - Red
2 - Yellow
3 - Green
4 - Cyan (Aqua)
5 - Blue
6 - Magenta
7 - Orange
8 - Purple
9 - White
0 - Random
S - (optional), speed setting integer for the Dim Pulse LED function below (0-9)
P - (optional), the Position integer value from list below:
Preset Position Integer Values
0 = Down
1 = Center
2 = Up
3 = Left
4 = Upper Left
5 = Lower Left
6 = Right
7 = Upper Right
8 = Lower Right
Some Simple Examples:
“R0053”   - Rear HP LEDs set solid Green (R/0/05/3)
“F00369” - Front HP Dim Pulse in Magenta at speed 9 (F/0/03/6/9)
“T006”     - Starts Rainbow sequence on the Top HP LEDs. (T/0/06)
“A0971”   - Clears all HP LEDs and enables default auto LED twitch. (A/0/97/1)
“F1012”   - Sends the Front HP to preset position 2 (Up). (F/1/01/2)
“A1011”   - Sends all three HPs to preset position 1 (Center). (A/1/01/1)
“R103”     - Enables RC control (Up/Down axis) on Rear HP. (R/1/03)
“T199”     - Enables Servo auto twitch mode for Top HP. (T/1/99)
Important: Command strings sent via Serial communication require the addition of a carriage return character (\r) to the end of the command string.  So the command string “R0063” from the examples above, would become “R0063\r” when using serial communication.  This carriage-return character lets the system know it has reached the end of a command.
I2C communication does not require this extra character. Type “help” or “?” in Serial Monitor for built-in command help.

## Special Sequence Commands
The commands sent using the structure outlined in the last section only allow you to control either the LEDs or the Servos using any given command.  There are times when you would like to use a single command to trigger several different behaviors of both types at once without needing to stack commands.    Therefore, we use special or “S”-series commands that combine a number of individual type functions  and behaviors into a single complex sequence.
Currently we only have 7 of these special commands:
“S1” - Leia Mode:  Front HP moves to down position, Leia LED Sequence begins, and the other two HPs are disabled.
“S4” - Clear and Disable without “Off Color”:
Clear all LEDs, Disable Auto Servo and LED Twitch, Disables “Off Color” use.  Used to quickly stop all HP functions.
“S5” - Clear and Enable without “Off Color”
Clear all LEDs, Enable Auto Servo and Default LED Twitch,  Disables “Off Color” use.   Used to quickly reset all HP functions
“S6” - Clear and Enable without “Off Color”
Clear all LEDs, Enable Auto Servo and Random LED Twitch, . Disables “Off Color” use.   Used to quickly reset all HP functions.
“S7” - Clear and Disable with “Off Color”:
Clear all LEDs, Disable Auto Servo and LED Twitch, Enables “Off Color” use.  Used to quickly stop all HP functions.
“S8” - Clear and Enable with “Off Color”
Clear all LEDs, Enable Auto Servo and Default LED Twitch,  Enables “Off Color” use.   Used to quickly reset all HP functions
“S9” - Clear and Enable with “Off Color”
Clear all LEDs, Enable Auto Servo and Random LED Twitch, . Enables “Off Color” use.   Used to quickly reset all HP functions.

## Timed Commands
New to the v1.3 Sketch is the added ability to add a run time value to any command.  This allows you to dictate how long you wish the sequence to run before it halts, returning the system to its last know auto state.  This keeps you from needing to manually stop sequences with follow up commands.
To add a run time value, simply add a pipe character, | , followed by the number of seconds you want the sequence to run.   So, the following command….
```cpp
A006|45
```
…would run the Rainbow Sequence on all 3 HPs for 45 seconds, then clear and return to the prior auto state.
Note: This feature has little effect on servo commands as they are not usually a continuous function by default.

## Replacement Back Plug
In the event you need to print a plug, the model file can be found at: http://2gwd.com/FlthyHPs/Rear_Plug.
Important: I have some tips for getting the best results when printing this plug.

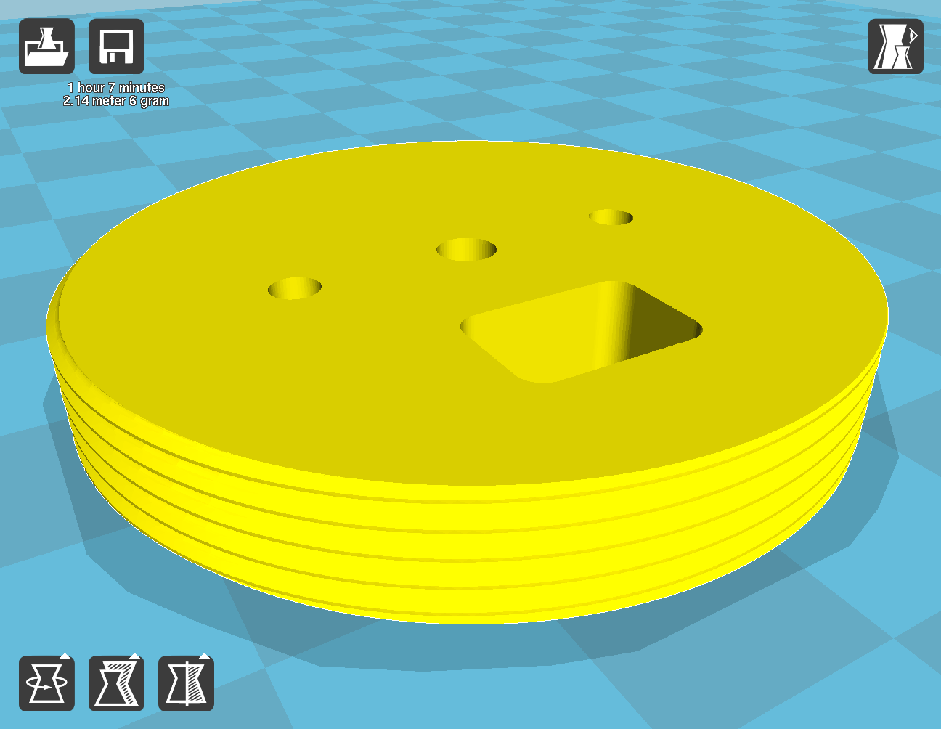
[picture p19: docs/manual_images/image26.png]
Manual image 15


First, if the model renders incredibly small in your 3d printing software, the units used are incorrect.  Just scale the size up by a factor of 25.4.
Second, before printing, orient the plug so that the holes with the beveled and recessed edges face down towards the build plate.  This will ensure the edge that must thread into the HP is printed cleanly.
Thirdly, when using Hatchbox brand 1.75mm PLA filament on my Printrbot Metal Plus, I have achieved good results using the following print setting.  Maybe you will too.
Layer Height: 0.1mm
Shell Thickness: 1.2mm
Bottom Thickness: 1.2mm
Fill Density: 30%
Print Speed: 40mm/s
Print Temp: 210C
Bed Temp: 50C
Flow: 100%
Nozzle Size: 0.4mm
Retraction Speed: 45mm/s
Retraction Distance 4.5mm
Initial Layer Thickness: 0.3mm
Initial line width: 100%
Bottom Layer Speed: 35mm/s
Cooling Fan: Enabled
Once printed, you will need to manually tap the center hole for M4 pattern bolt.  The two mounting holes for the Adafruit Jewel LED board will most likely need slightly enlarged with a drill accommodate M2 sized screws.
To assemble, I use 2-M2 Nylon Screws (cut to length), 2-M2 20mm male/female Nylon standoffs. and 2- M2 Nylon nuts to mount the NeoPixel Jewel to the Back plug.

## Finding Your Preset Servo Position Coordinates

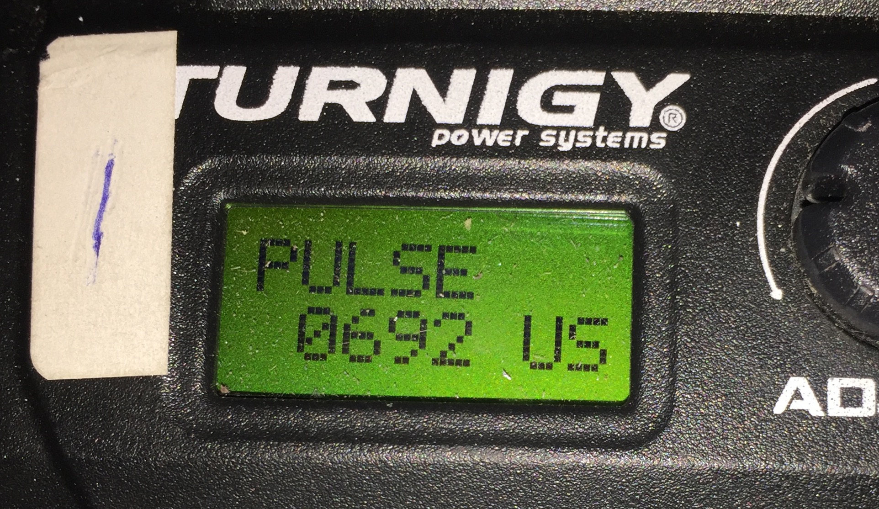
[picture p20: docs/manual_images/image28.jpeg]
Manual image 16


As mentioned previously in the explanation of the sketch’s HP position variable array, this system works best when we provide a complete set of 6 predetermined coordinate pairs per HP corresponding to specific position, namely the Down, Center, and Up positions along with 3 additional auxiliary positions.
I have found the easiest way to do the is to use a set of servo testers with digital displays.  These servo testers will allow us to manually move each HP into the various positions and then quickly gather the two pulse width values in microseconds that make up each coordinate pair.
I used a pair of G.T. Power Digital Servo Performance testers to gather my coordinates pretty quickly once my HPs were mounted in my dome and the control linkage installed.  A pair of these can be purchased for less than $50 from Banggood here:

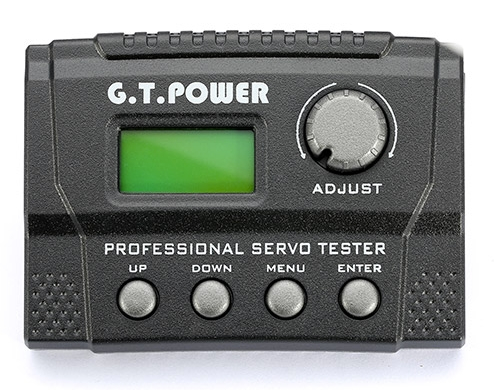
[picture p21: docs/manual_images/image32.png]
Manual image 17


<http://www.banggood.com/G_T_Power-Digital-Servo-Performance-Tester-p-999251.html>
Before you begin, I must make it clear your HPs need to be mounted with servo plates/linkage in place.  These values are dependent on several variables and removing your HPs or their linkage you will more than likely require you to perform this process again.
First, take a piece of masking tape or a stick-on label and number your two servo testers “1” and “2”.  This ensures the values gathered aren’t mixed up.  Tester “1” will always provide the first value in the coordinate pair, and tester “2” will provide the second value.
Next, locate the two servos for your first HP.  (It is probably most efficient to start with the Front HP.)  Plug one of the servos into Tester “1” and the other servo into Tester “2”.
Remember the orientation of the servos in relation to how they are mounted in the dome along with which tester you connected to them.  You want to maintain the special relationship when moving on to the other two HPs.   This will help keep things consistent.
Using the up/down and menu/enter keys on each servo tester, you will want to select “Analog”->”LN Mode”->”Extend”.  This will take you to a screen that reads “PULSE” with a 4 digit number followed by “US” (which stands for microseconds).  You may have also noticed that once you reached this screen, the HP servos moved a bit, that is because you can now control the PWM values being sent to each servo.
Use the “Adjust” knob on each servo tester to move its respective servo. Using both in unison will allow you to move the HP to specific positions.  Feel free to mess around and get a feel for it.
Once you are ready to collect your position coordinates, move the HP to the location you would like to assign as the Down position.  Once you are happy with the HP’s orientation, record the value shown on the screen of tester “1” followed by the value seen on tester “2”.  You now have collected your first position coordinate pair.
Repeat this process to determine the coordinates for the HP’s Center and Up positions.  Once these first 3 coordinates are completed, you will then need to collect coordinates for the 3 auxiliary positions.  These positions can be anywhere you wish as long as they lie safely in the range of motion of your HP. These are used to provide random movements different than the standard Down/Center/Up positions, but with the added benefit of being safe from impeding movement which could cause excessive noise or binding.
After collecting these last three auxiliary position coordinates, you have a complete set of positions for this HP and you can move on to the next, repeating the process.
Once you have completed collecting your position data for all three HPs, you will need to add them to the HPpos variable array in your custom copy of the FlthyHP Arduino sketch.
As suggested before, I strongly suggest you also save these values separately from your sketch. That way if you ever need to reinstall the sketch or a new version of the sketch is released, you don't need to go through these steps again.
It is probably a good idea to occasionally recollect this data as things get pulled on and tweaked in a manner that can gradually throw your alignment off in one direction or the other.  Think of it as a sort of regular maintenance need of Artoo.

## Build it Yourself
Open Source/Hardware Because Sharing is Caring
I believe that by freely sharing my hardware design files, Arduino sketch, and 3d models in the spirit of open hardware and software, we can continue to build better droids.
I will continue to host all current digital files for this system online at the following location:  http://www.2geekswebdesign.com/FlthyHPs/
*The only file I currently don’t have is the EagleCad BRD file for the Arduino Pro Mini Breakout Board because I accidentally deleted it after submitting it to Oshpark for initial fabrication.  However, it is shared at Oshpark so you can order it from them at: https://oshpark.com/shared_projects/EGLjaD6I
The Rules
These files are shared for personal use only.   You may not offer/sell a system using my design in part or whole without my express permission.
I offer no warranty or liability for those choosing to build their own from the files provided.  Doing so requires a basic familiarity with soldering small components, the knowledge to install an Arduino sketch, and use/access to a 3D printer.  If you don’t have these skills or know someone who is willing to help you learn, I advise not attempting this build.   I simply don’t have the time each day to answer questions regarding the prerequisite skill sets needed to accomplish this build.
Thus…I offer complete assembled and tested systems for those not wishing to construct their own!

## How to Update & Flash Sketch on Arduino Pro Mini
Download and install the current version of the Arduino IDE software from https://www.arduino.cc/en/Main/Software
Download current sketch from http://2gwd.com/FlthyHPs/Sketches/
Download the current version of the required Adafruit Neopixel library from https://github.com/adafruit/Adafruit_NeoPixel.
Download the current version of the required Adafruit PWM Servo Driver library from https://github.com/adafruit/Adafruit-PWM-Servo-Driver-Library.
Download the current version of the required BHD Slow Servo library from https://drive.google.com/file/d/0B5B8A65frsBgZ3VpeGxpM1lzaFE/edit.
Extract each of the three downloaded libraries into the “libraries” directory of your Arduino IDE installation.  They should stay in their individual folders inside the “libraries” directory.   See Image Below

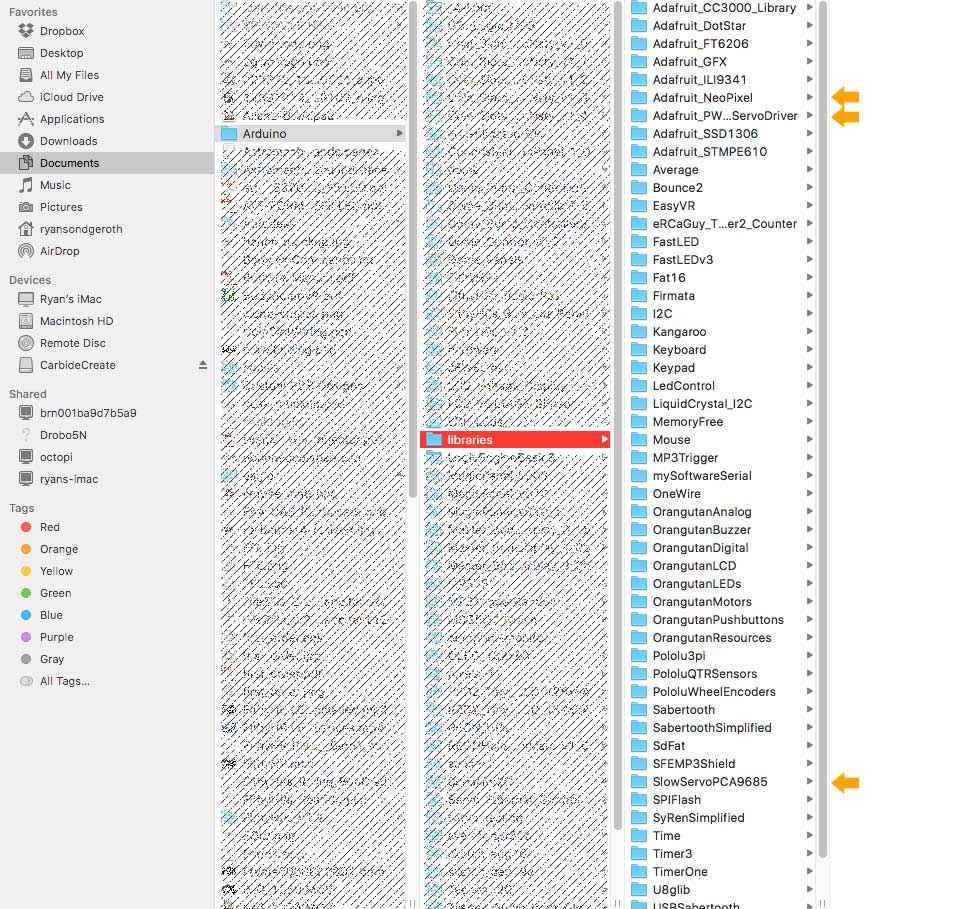
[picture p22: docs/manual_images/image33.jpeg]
Manual image 18


Open the downloaded FlthyHP sketch using the Arduino IDE software.  You may be prompted to create a new directory for the sketch if it is the first time opening it, select ok.  After this initial time, you can access the saved sketch through the file drop down menu within the Arduino IDE software.
Make any desired changes to the sketch settings as explained in this manual.
Once changes are made, plug your FTDI programmer into your computers USB port.  Your programmer may be different as there is a multitude of options available, but I use a FTDI Friend from Adafruit.  Some selections in the steps below may be different based on the programmer you are using.

Manual image 19

Next plug your FTDI programmer into the 6 pin holes on the end of the Arduino Pro Mini.  Make sure you align the holes correctly as different models have the pin holes ordered differently.  Make sure the Tx pin on the FTDI programmer is plugged in to the Rx pin of the Arduino Pro Mini.  Likewise, the Rx pin of the FTDI programmer is plugged into the Tx pin of the Arduino Pro Mini.  The Arduino’s power LED should light up if power is correctly applied over USB through the programmer.   See Image ->
In the Arduino IDE menu, select Tools->Board and ensure “Arduino Pro or Pro Mini” is selected from the board list. See Image Below.

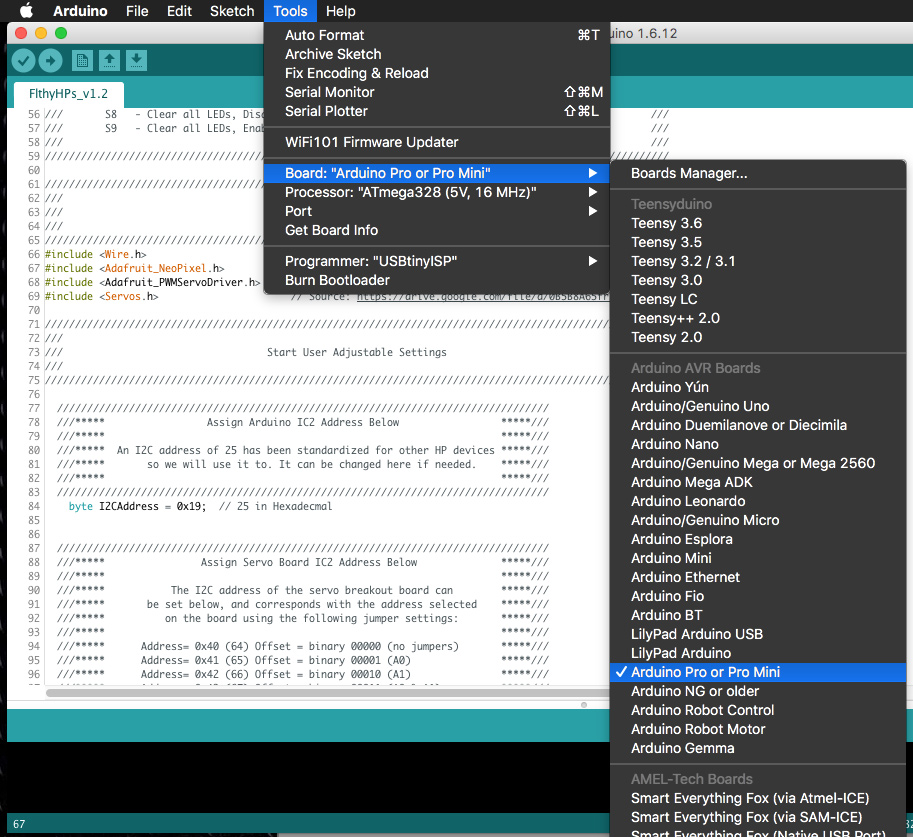
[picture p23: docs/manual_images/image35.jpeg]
Manual image 20


Likewise, in the Arduino IDE menu, select Tools->Port and select the port of the programmer you just connected.  It should have a name like “COM#” on a Windows machine or something like “cu-usbserial-XXXXXXX” on a Macintosh/Linux machine.  If no port shows up when connecting your programmer, you may need to install the correct drivers for your programmer.  This guide does not tackle that process as it is dependent on OS and programmer.  Refer to the programmer’s documentation for instructions. See Image Below

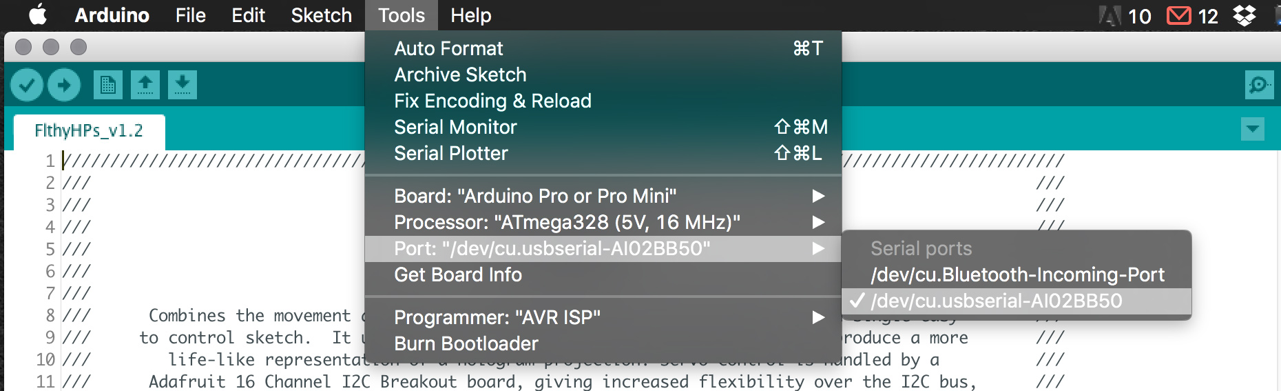
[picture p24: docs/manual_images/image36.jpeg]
Manual image 21


At this point you are ready to upload the new sketch.  Select the upload button in the upper left corner of the Arduino IDE software window.  There are two steps to this process.   First, the software will verify the sketch ensuring there are no issues and errors.  If no errors are found the sketch is then compiled into machine code and uploaded/flashed to the Arduino Pro Mini.  This should only take a few moments, maybe 10 to 30 seconds max.  Watch the progress bar at the bottom of the software’s window, you will receive confirmation when the process is complete.  If there are any errors, they will appear in the lower black window of the software’s interface.  Most errors have to do with incorrect syntax or improperly installed libraries.
At this point you are done and the sketch has been updated.

## Using the FlthyHPs with Marcduino v1.5/v2
For those wishing to utilize their MarcDuino v1.5 or v2 boards and the R2-Touch app to control their FlthyHPs,  Marc added I2C communication support to his system and a pretty slick command structure to facilitate it.
To get started, you will first need to ensure you have both the MarcDuino Master board and the FlthyHPs board connected via the I2C pins.  This is accomplished by simply connecting….

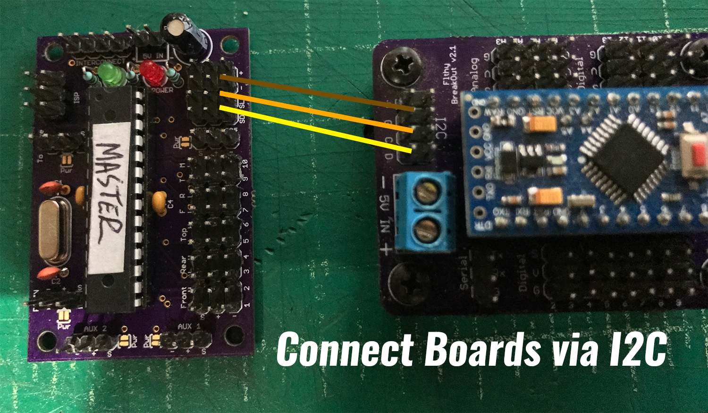
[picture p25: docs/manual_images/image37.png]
Manual image 22


the MarcDuino SDA pin to the the FlthyHP D pin,
the MarcDuino SCL pin the the FlthyHP C pin,
and the MarcDuino - (ground) pin to the FlthyHP G pin.
Note: Connecting the voltage pins between the two isn’t necessary but you can do so if you wish to power one boards via the other.  I however recommend you power each board separately from a quality 5v power supply capable of providing 5amps+.   Optimal performance can only be achieved if both systems are provided ample, stable power.
Also, I don’t recommend using the I2C pins on the Slave board to connect to the FlthyHPs because there is default behavior in the MarcDuino source code for communicating with the REON HP system.  Both the front REON HP and the FlthyHP system use an I2C address of 0x19 (25) and this causes issues.  If you must use the I2C of the MarcDuino slave or have both systems and wish to run them in unison, you can change the I2C address in the FlthyHPs sketch rather easily to remove this conflict.  Simply assign it a value not currently in use on your I2C bus, making sure to reference this new address in the command structure explained below.

### MarcDuino I2C Commands
Marc’s I2C command structure allows for a user to send many different data types, but the FlthyHP command structure utilizes string commands only, so I will only cover this command format here.  If you wish to learn more about Marc’s entire command structure, visit the documentation on his web site here.
To send a command via I2C to your FlthyHPs, your MarcDuino utilizes the following command structure:
```cpp
&25,"A006|10\r
```
Ok…It may seem confusing at first glance, but I assure you it isn’t.  Let’s break it down for you.
& is the character specifying the command is an I2C command.
25 is the I2C address of the target device in decimal format.
,  (The comma) is a delimiter between the address information and the command information.
" (Double quote) tells the MarcDuino you want to send a String command to the FlthyHPs.
```cpp
A006|10 is the FlthyHP command string you want to send but you already knew that because you read the section covering it earlier in this very manual.  In this case it is the command to set all 3 HPs to the Rainbow LED sequence and run it for 10 seconds.
```
\r is the equivalent of the carriage return character and is utilized by the MarcDuino to signify the end of a command.  All commands for your MarcDuino must end with this character.
Please Note:  There is no closing or trailing double quote in this sequence as it is not required.

### Stringing or Combining Multiple Commands
Often you may want to assign multiple commands to a single button in the R2 Touch app as a way off constructing more elaborate droid sequences.  Marc had the forethought to add this functionality to his command structure.   You can simply add additional commands to your string, keeping each separated by the trailing carriage return character (\r).
So taking the command example above, &25,"A006|10\r, we could add the command to open all Artoo’s dome panels, :OP00\r.  So, your new combined command would become &25,"A006|10\r:OP00\r.  Simple enough.
However, in some cases depending on the amount of processing time required for each command, you may need to introduce a brief pause between the execution of each command.  You can do so easily by adding one or more \p between your commands in the string.
I have found in my testing this is often the case when sending command to the FlthyHPs, so our command grows just a touch longer to become &25,"A006|10\r\p\p\p:OP00\r.
You will notice I added three \p to the command string following the first command’s carriage return to pause things briefly, giving the system time to process everything correctly.
You will have to do some testing yourself, as it isn’t possible to know every possible combination you guys come up with.  But a little trial and error will help you get an idea of how best to handle your specific set up.

### R2 Touch App
I am not going to go into much depth regarding the process for adding and assigning custom commands to the R2 Touch mobile app.  Marc has provided wonderful documentation regarding the process on his web site here:
<http://www.curiousmarc.com/r2-touch-r2-d2-remote-control-iphone-app/customizing-r2-touch>
That’s all there is to getting these two systems working together.  I hope you guys find my explanation clear and helpful.

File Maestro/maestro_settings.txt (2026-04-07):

<!--Pololu Maestro servo controller settings file, http://www.pololu.com/catalog/product/1350-->
<UscSettings version="1">
  <NeverSuspend>false</NeverSuspend>
  <SerialMode>UART_FIXED_BAUD_RATE</SerialMode>
  <FixedBaudRate>19200</FixedBaudRate>
  <SerialTimeout>0</SerialTimeout>
  <EnableCrc>false</EnableCrc>
  <SerialDeviceNumber>12</SerialDeviceNumber>
  <SerialMiniSscOffset>0</SerialMiniSscOffset>
  <Channels ServosAvailable="6" ServoPeriod="156">
    <!--Period = 19.968 ms-->
    <!--Channel 0-->
    <Channel name="" mode="Servo" min="4800" max="7200" homemode="Goto" home="6000" speed="0" acceleration="0" neutral="6000" range="2400" />
    <!--Channel 1-->
    <Channel name="" mode="Servo" min="4800" max="7200" homemode="Goto" home="6000" speed="0" acceleration="0" neutral="6000" range="2400" />
    <!--Channel 2-->
    <Channel name="" mode="Servo" min="4800" max="7200" homemode="Goto" home="6000" speed="0" acceleration="0" neutral="6000" range="2400" />
    <!--Channel 3-->
    <Channel name="" mode="Servo" min="4800" max="7200" homemode="Goto" home="6000" speed="0" acceleration="0" neutral="6000" range="2400" />
    <!--Channel 4-->
    <Channel name="" mode="Servo" min="4800" max="7200" homemode="Goto" home="6000" speed="0" acceleration="0" neutral="6000" range="2400" />
    <!--Channel 5-->
    <Channel name="" mode="Servo" min="4800" max="7200" homemode="Goto" home="6000" speed="0" acceleration="0" neutral="6000" range="2400" />
  </Channels>
  <Sequences />
  <Script ScriptDone="true">
# ============================================================
# FlthyHPs Maestro Script
# by Ryan Sondgeroth / FlthyMcNsty
#
# 3 HPs x 9 base positions = 27 subroutines
# Subroutine index = (hp * 9) + position
#   HP1 (Front) = subroutines  0 -  8   channels 0, 1
#   HP2 (Rear)  = subroutines  9 - 17   channels 2, 3
#   HP3 (Top)   = subroutines 18 - 26   channels 4, 5
# Do not edit subroutines 0-26 unless you are changing the built-in base
# positioning table. Add custom routines starting at subroutine 27 and above.
# Shared pose helpers are listed last so the position values stay centralized.
#
# Position layout (matches HP_POSITIONS order in sketch):
#   0 = center
#   1 = up
#   2 = down
#   3 = left
#   4 = upper-left
#   5 = lower-left
#   6 = right
#   7 = upper-right
#   8 = lower-right
#
# Values are in quarter-microseconds (us x 4).
# 1500us center = 6000 quarter-us.
#
# To calibrate: use Maestro Control Center Status tab sliders
# to jog each servo pair to each desired position, note the
# pulse width values, multiply by 4, and update below.
# No sketch changes needed after updating these base position values.
# ============================================================

# --- HP1 (Front)  channels 0, 1 ---

sub hp1_center        # subroutine 0
  6000 0 servo        # ch0 = 1500us
  6000 1 servo        # ch1 = 1500us
  quit

sub hp1_up            # subroutine 1
  7000 0 servo        # ch0 = 1750us
  6000 1 servo        # ch1 = 1500us
  quit

sub hp1_down          # subroutine 2
  5000 0 servo        # ch0 = 1250us
  6000 1 servo        # ch1 = 1500us
  quit

sub hp1_left          # subroutine 3
  6000 0 servo        # ch0 = 1500us
  7000 1 servo        # ch1 = 1750us
  quit

sub hp1_upper_left    # subroutine 4
  6500 0 servo        # ch0 = 1625us
  6500 1 servo        # ch1 = 1625us
  quit

sub hp1_lower_left    # subroutine 5
  6500 0 servo        # ch0 = 1625us
  5500 1 servo        # ch1 = 1375us
  quit

sub hp1_right         # subroutine 6
  6000 0 servo        # ch0 = 1500us
  5000 1 servo        # ch1 = 1250us
  quit

sub hp1_upper_right   # subroutine 7
  6500 0 servo        # ch0 = 1625us
  5500 1 servo        # ch1 = 1375us
  quit

sub hp1_lower_right   # subroutine 8
  5500 0 servo        # ch0 = 1375us
  5500 1 servo        # ch1 = 1375us
  quit

# --- HP2 (Rear)  channels 2, 3 ---

sub hp2_center        # subroutine 9
  6000 2 servo        # ch2 = 1500us
  6000 3 servo        # ch3 = 1500us
  quit

sub hp2_up            # subroutine 10
  7000 2 servo        # ch2 = 1750us
  6000 3 servo        # ch3 = 1500us
  quit

sub hp2_down          # subroutine 11
  5000 2 servo        # ch2 = 1250us
  6000 3 servo        # ch3 = 1500us
  quit

sub hp2_left          # subroutine 12
  6000 2 servo        # ch2 = 1500us
  7000 3 servo        # ch3 = 1750us
  quit

sub hp2_upper_left    # subroutine 13
  6500 2 servo        # ch2 = 1625us
  6500 3 servo        # ch3 = 1625us
  quit

sub hp2_lower_left    # subroutine 14
  6500 2 servo        # ch2 = 1625us
  5500 3 servo        # ch3 = 1375us
  quit

sub hp2_right         # subroutine 15
  6000 2 servo        # ch2 = 1500us
  5000 3 servo        # ch3 = 1250us
  quit

sub hp2_upper_right   # subroutine 16
  5144 2 servo        # ch2 = 1286us
  6408 3 servo        # ch3 = 1602us
  quit

sub hp2_lower_right   # subroutine 17
  5500 2 servo        # ch2 = 1375us
  5500 3 servo        # ch3 = 1375us
  quit

# --- HP3 (Top)  channels 4, 5 ---

sub hp3_center        # subroutine 18
  6000 4 servo        # ch0 = 1500us
  6000 5 servo        # ch1 = 1500us
  quit

sub hp3_up            # subroutine 19
  7000 4 servo        # ch4 = 1750us
  6000 5 servo        # ch5 = 1500us
  quit

sub hp3_down          # subroutine 20
  5000 4 servo        # ch4 = 1250us
  6000 5 servo        # ch5 = 1500us
  quit

sub hp3_left          # subroutine 21
  6000 4 servo        # ch4 = 1500us
  7000 5 servo        # ch5 = 1750us
  quit

sub hp3_upper_left    # subroutine 22
  6500 4 servo        # ch4 = 1625us
  6500 5 servo        # ch5 = 1625us
  quit

sub hp3_lower_left    # subroutine 23
  6500 4 servo        # ch4 = 1625us
  5500 5 servo        # ch5 = 1375us
  quit

sub hp3_right         # subroutine 24
  6000 4 servo        # ch4 = 1500us
  5000 5 servo        # ch5 = 1250us
  quit

sub hp3_upper_right   # subroutine 25
  6500 4 servo        # ch4 = 1625us
  5500 5 servo        # ch5 = 1375us
  quit

sub hp3_lower_right   # subroutine 26
  5500 4 servo        # ch4 = 1375us
  5500 5 servo        # ch5 = 1375us
  quit

# --- Custom Maestro subroutines start here ---
# Trigger from the Arduino with M27, M28, etc.
# Add custom behavior here. These routines can reuse the shared pose helpers
# below so you only maintain each position value in one place.
# This example walks all three HPs clockwise together starting at up.

sub hp_all_clockwise_tour # subroutine 27
  hp1_up_pose
  hp2_up_pose
  hp3_up_pose
  500 delay

  hp1_upper_right_pose
  hp2_upper_right_pose
  hp3_upper_right_pose
  500 delay

  hp1_right_pose
  hp2_right_pose
  hp3_right_pose
  500 delay

  hp1_lower_right_pose
  hp2_lower_right_pose
  hp3_lower_right_pose
  500 delay

  hp1_down_pose
  hp2_down_pose
  hp3_down_pose
  500 delay

  hp1_lower_left_pose
  hp2_lower_left_pose
  hp3_lower_left_pose
  500 delay

  hp1_left_pose
  hp2_left_pose
  hp3_left_pose
  500 delay

  hp1_upper_left_pose
  hp2_upper_left_pose
  hp3_upper_left_pose
  500 delay

  hp1_up_pose
  hp2_up_pose
  hp3_up_pose
  quit

# --- Shared pose helpers ---
# These are intentionally listed last. Update these numeric targets here when
# calibrating positions; the base wrappers and custom routines both call these
# helpers so the values stay centralized.

sub hp1_center_pose
  6000 0 servo        # ch0 = 1500us
  6000 1 servo        # ch1 = 1500us
  return

sub hp1_up_pose
  7000 0 servo        # ch0 = 1750us
  6000 1 servo        # ch1 = 1500us
  return

sub hp1_down_pose
  5000 0 servo        # ch0 = 1250us
  6000 1 servo        # ch1 = 1500us
  return

sub hp1_left_pose
  6000 0 servo        # ch0 = 1500us
  7000 1 servo        # ch1 = 1750us
  return

sub hp1_upper_left_pose
  6500 0 servo        # ch0 = 1625us
  6500 1 servo        # ch1 = 1625us
  return

sub hp1_lower_left_pose
  6500 0 servo        # ch0 = 1625us
  5500 1 servo        # ch1 = 1375us
  return

sub hp1_right_pose
  6000 0 servo        # ch0 = 1500us
  5000 1 servo        # ch1 = 1250us
  return

sub hp1_upper_right_pose
  6500 0 servo        # ch0 = 1625us
  5500 1 servo        # ch1 = 1375us
  return

sub hp1_lower_right_pose
  5500 0 servo        # ch0 = 1375us
  5500 1 servo        # ch1 = 1375us
  return

sub hp2_center_pose
  6000 2 servo        # ch2 = 1500us
  6000 3 servo        # ch3 = 1500us
  return

sub hp2_up_pose
  7000 2 servo        # ch2 = 1750us
  6000 3 servo        # ch3 = 1500us
  return

sub hp2_down_pose
  5000 2 servo        # ch2 = 1250us
  6000 3 servo        # ch3 = 1500us
  return

sub hp2_left_pose
  6000 2 servo        # ch2 = 1500us
  7000 3 servo        # ch3 = 1750us
  return

sub hp2_upper_left_pose
  6500 2 servo        # ch2 = 1625us
  6500 3 servo        # ch3 = 1625us
  return

sub hp2_lower_left_pose
  6500 2 servo        # ch2 = 1625us
  5500 3 servo        # ch3 = 1375us
  return

sub hp2_right_pose
  6000 2 servo        # ch2 = 1500us
  5000 3 servo        # ch3 = 1250us
  return

sub hp2_upper_right_pose
  5144 2 servo        # ch2 = 1286us
  6408 3 servo        # ch3 = 1602us
  return

sub hp2_lower_right_pose
  5500 2 servo        # ch2 = 1375us
  5500 3 servo        # ch3 = 1375us
  return

sub hp3_center_pose
  6000 4 servo        # ch4 = 1500us
  6000 5 servo        # ch5 = 1500us
  return

sub hp3_up_pose
  7000 4 servo        # ch4 = 1750us
  6000 5 servo        # ch5 = 1500us
  return

sub hp3_down_pose
  5000 4 servo        # ch4 = 1250us
  6000 5 servo        # ch5 = 1500us
  return

sub hp3_left_pose
  6000 4 servo        # ch4 = 1500us
  7000 5 servo        # ch5 = 1750us
  return

sub hp3_upper_left_pose
  6500 4 servo        # ch4 = 1625us
  6500 5 servo        # ch5 = 1625us
  return

sub hp3_lower_left_pose
  6500 4 servo        # ch4 = 1625us
  5500 5 servo        # ch5 = 1375us
  return

sub hp3_right_pose
  6000 4 servo        # ch4 = 1500us
  5000 5 servo        # ch5 = 1250us
  return

sub hp3_upper_right_pose
  6500 4 servo        # ch4 = 1625us
  5500 5 servo        # ch5 = 1375us
  return

sub hp3_lower_right_pose
  5500 4 servo        # ch4 = 1375us
  5500 5 servo        # ch5 = 1375us
  return
  </Script>
</UscSettings>

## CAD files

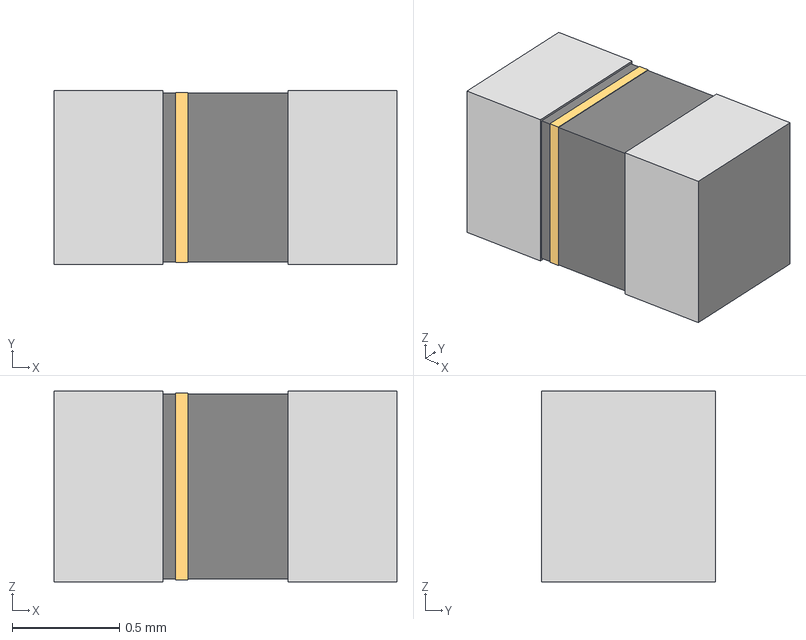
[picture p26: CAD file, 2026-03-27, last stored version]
G-188_MUR.step
1.60 x 0.812 x 0.889 mm

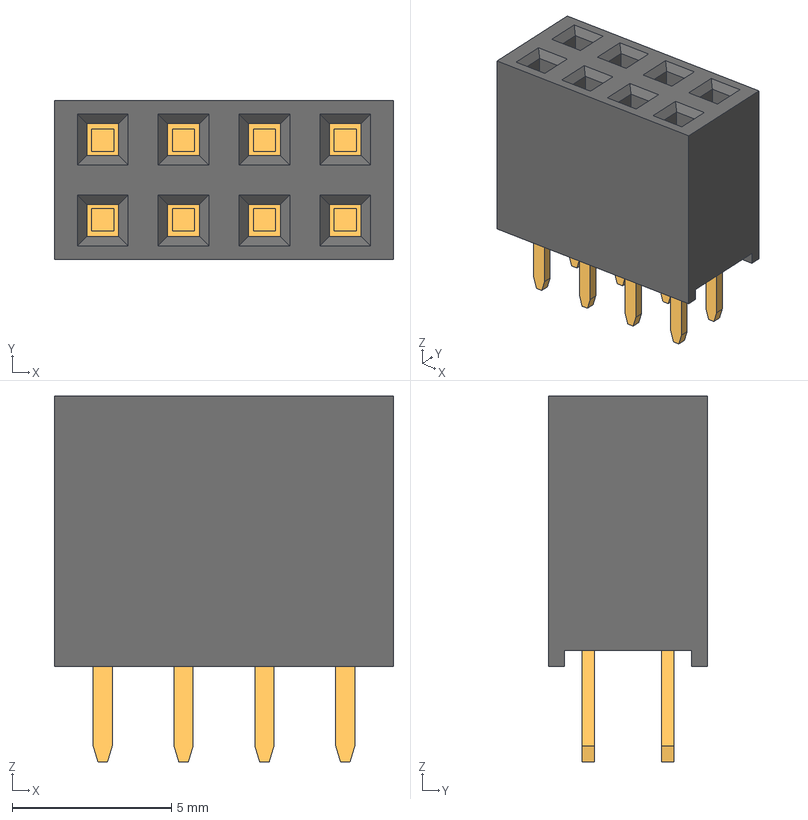
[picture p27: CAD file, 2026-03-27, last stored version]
Maestro/hardware/kicad_libraries/3d_models/headers/8Pin_Header_Female_Double_2p54mm.step
10.7 x 5.00 x 11.5 mm

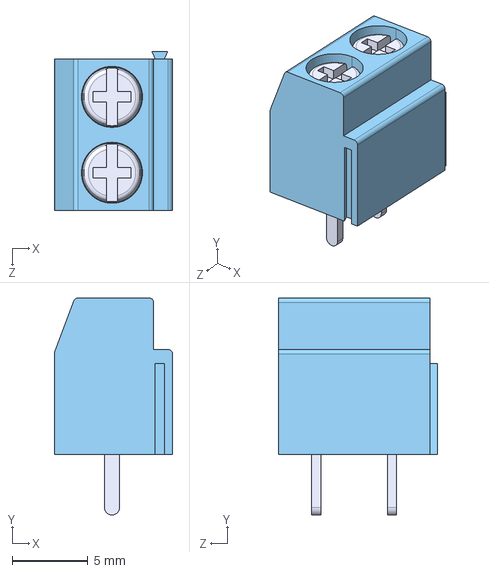
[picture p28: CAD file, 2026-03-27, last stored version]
Maestro/hardware/kicad_libraries/3d_models/TB003-500-P02BE--3DModel-STEP-1.STEP
7.80 x 14.3 x 10.5 mm

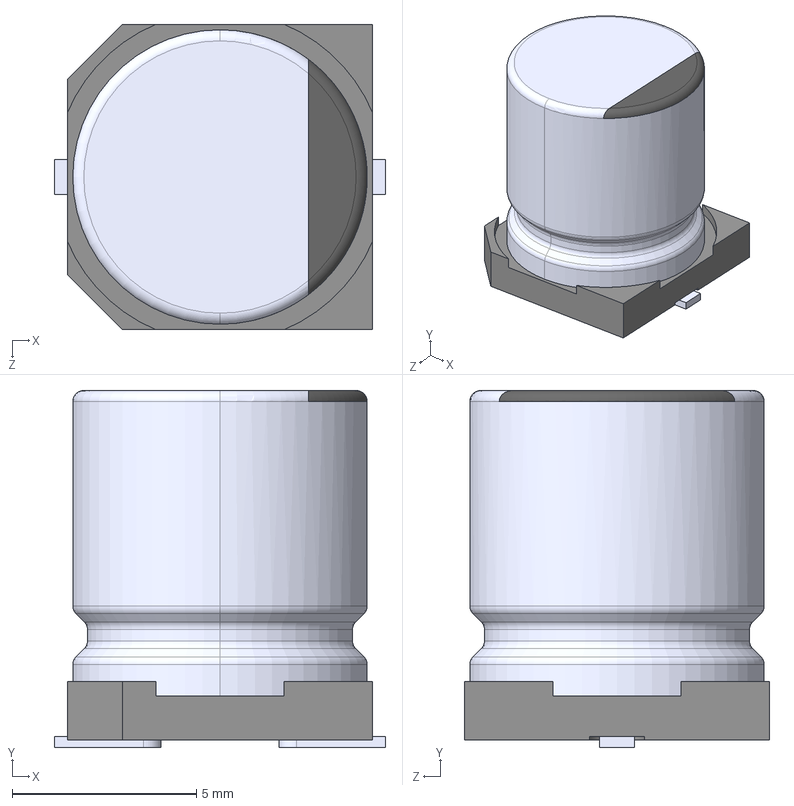
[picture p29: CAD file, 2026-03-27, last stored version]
A767KN476M1HLAE029.step
9.00 x 9.70 x 8.30 mm

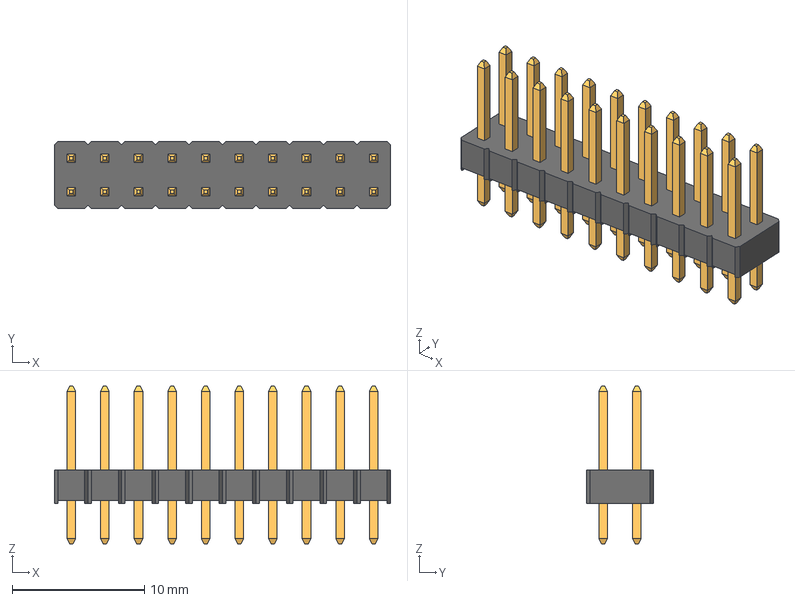
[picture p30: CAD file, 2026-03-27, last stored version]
Maestro/hardware/kicad_libraries/3d_models/headers/20Pin_Header_Male_Double_2p54mm.step
25.4 x 5.08 x 11.9 mm

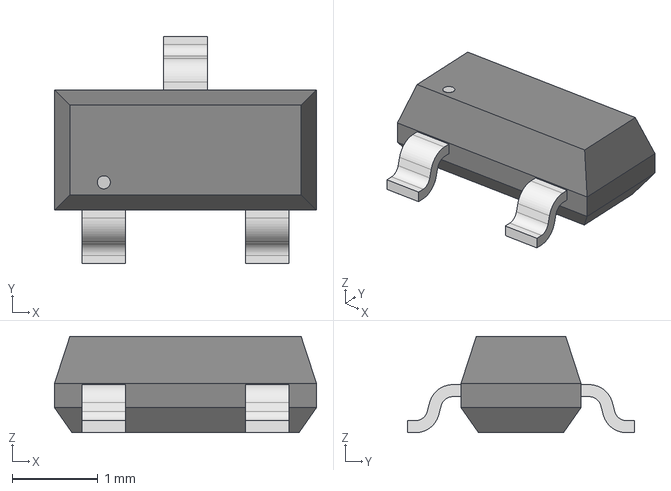
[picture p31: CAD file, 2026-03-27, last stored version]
Maestro/hardware/kicad_libraries/3d_models/TO-236_VIS.step
3.05 x 2.64 x 1.12 mm

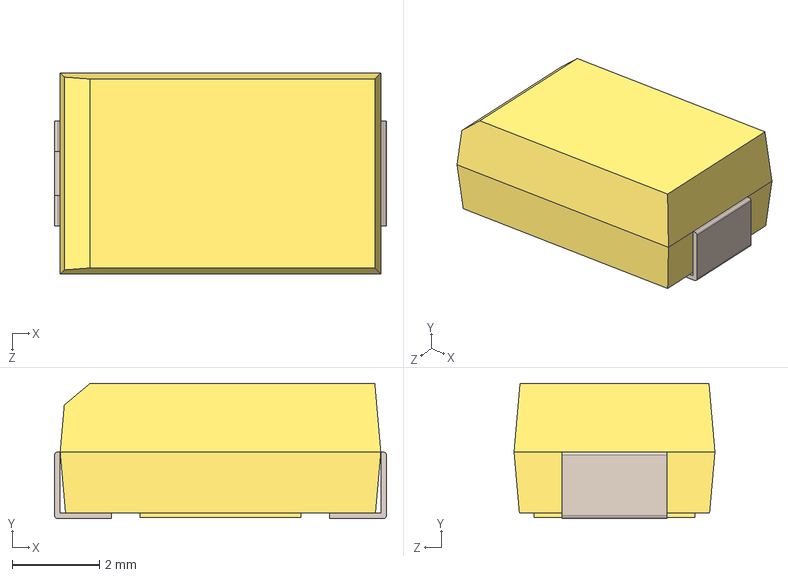
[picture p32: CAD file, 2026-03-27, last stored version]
Maestro/hardware/kicad_libraries/3d_models/CTS_7343_L7.60W4.60H3.10S1.3F2.4R1P0.9B0.5.step
7.60 x 3.10 x 4.60 mm
Case_Bottom_21
Case_Top_21
Case_Cathode_21
Case_Anode_21

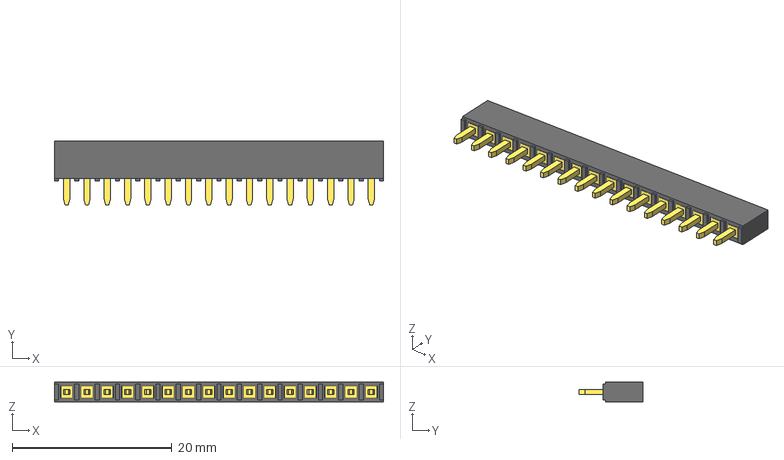
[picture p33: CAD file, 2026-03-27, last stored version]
Maestro/hardware/kicad_libraries/3d_models/headers/16Pin_Header_Female_2p54mm.step
41.1 x 8.00 x 2.50 mm

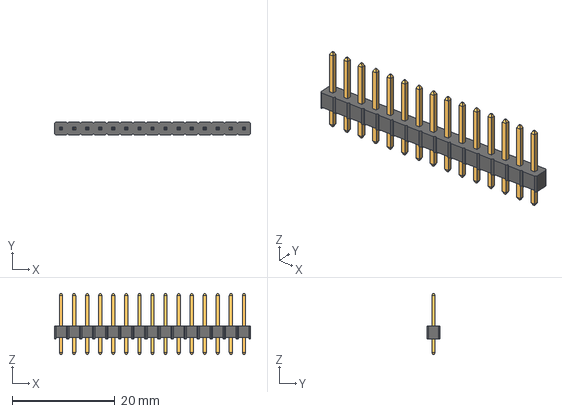
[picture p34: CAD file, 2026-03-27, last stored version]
Maestro/hardware/kicad_libraries/3d_models/headers/15Pin_Header_Male_2p54mm.step
38.1 x 2.54 x 11.9 mm

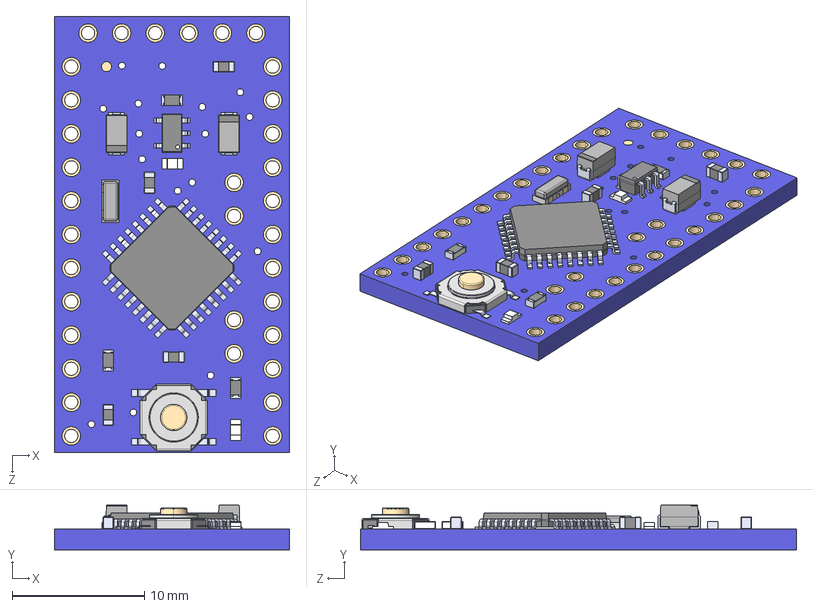
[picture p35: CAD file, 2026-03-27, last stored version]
Maestro/hardware/kicad_libraries/3d_models/Arduino Pro Mini--3DModel-STEP-510211.STEP
17.8 x 3.37 x 33.0 mm
Arduino Pro Mini_Board
SMD-ALT01
ATMEGA328_ATMEGA168
RESONATOR1_1
CAP_POL1206 x 2
V_REG_LDOSMD
RESISTOR0603-RES x 3
CAP0603-CAP x 4

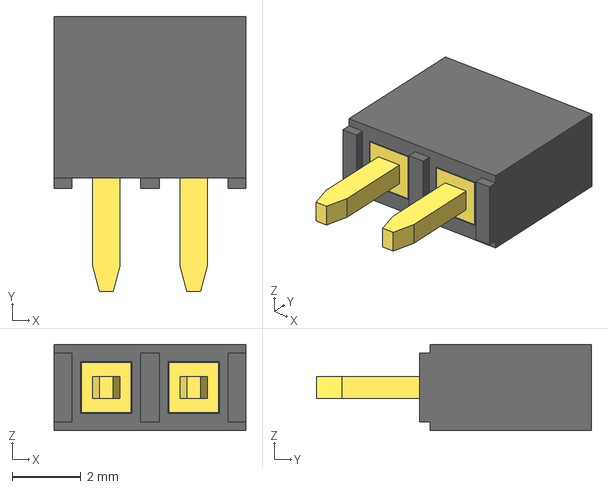
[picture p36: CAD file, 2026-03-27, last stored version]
Maestro/hardware/kicad_libraries/3d_models/headers/2Pin_Header_Female_2p54mm.step
5.58 x 8.00 x 2.50 mm

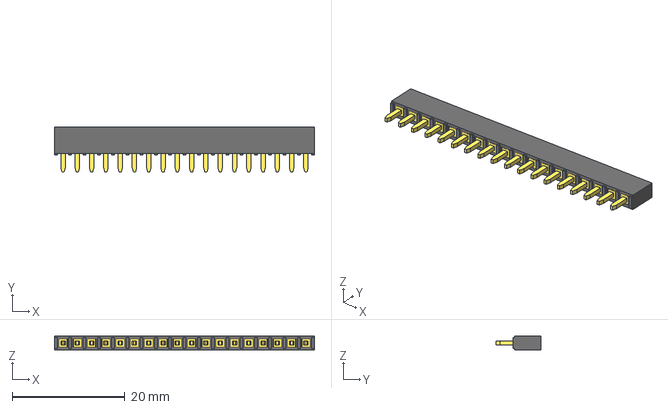
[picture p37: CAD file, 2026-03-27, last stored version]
Maestro/hardware/kicad_libraries/3d_models/headers/18Pin_Header_Female_2p54mm.step
46.2 x 8.00 x 2.50 mm

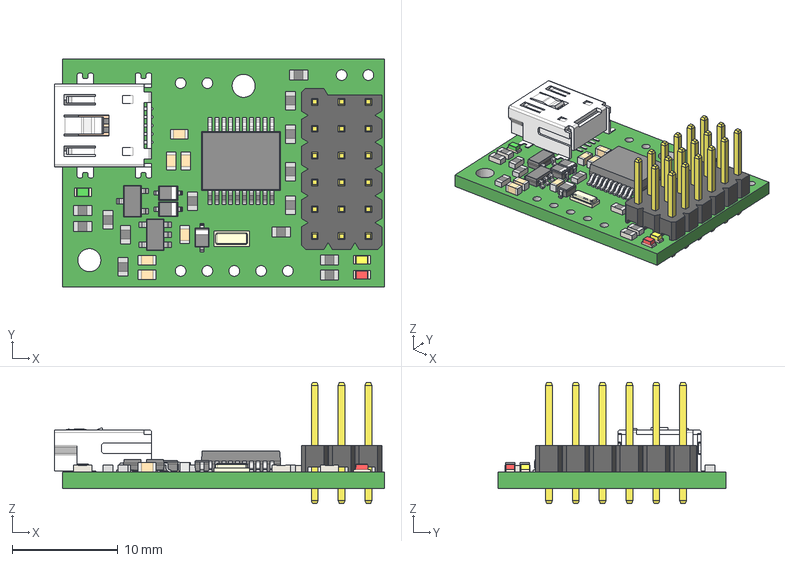
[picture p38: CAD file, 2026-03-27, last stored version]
Maestro/hardware/kicad_libraries/3d_models/micro-maestro-6-channel-usb-servo-controller(1).step
31.2 x 21.6 x 11.5 mm

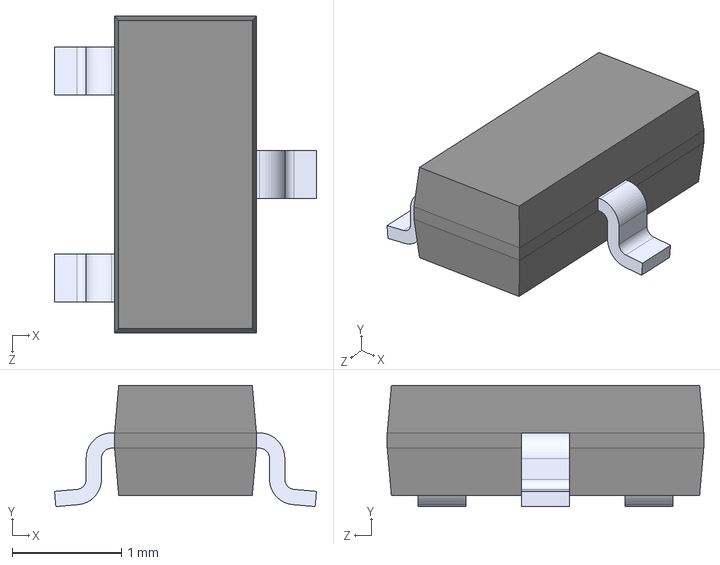
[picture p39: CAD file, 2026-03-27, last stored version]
Maestro/hardware/kicad_libraries/3d_models/BZX84C5V1LT1G.STEP
2.40 x 1.11 x 2.90 mm

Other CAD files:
Maestro/hardware/kicad_libraries/3d_models/headers/28Pin_Header_Male_Double_2p54mm.step
Maestro/hardware/kicad_libraries/3d_models/d42v55fx-step-down-voltage-regulator.step
Maestro/hardware/kicad_libraries/3d_models/headers/4Pin_Header_Male_Double_2p54mm.step
Maestro/hardware/kicad_libraries/3d_models/MF-MSMF050-2--3DModel-STEP-56544.STEP
Maestro/hardware/kicad_libraries/3d_models/headers/10Pin_Header_Female_2p54mm.step
Maestro/hardware/kicad_libraries/3d_models/headers/10Pin_Header_Female_Double_2p54mm.step
Maestro/hardware/kicad_libraries/3d_models/headers/10Pin_Header_Male_2p54mm.step
Maestro/hardware/kicad_libraries/3d_models/headers/10Pin_Header_Male_Double_2p54mm.step
Maestro/hardware/kicad_libraries/3d_models/headers/11Pin_Header_Female_2p54mm.step
Maestro/hardware/kicad_libraries/3d_models/headers/11Pin_Header_Male_2p54mm.step
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

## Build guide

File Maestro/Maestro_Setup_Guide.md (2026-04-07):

# FlthyHPs Maestro Setup Guide
### Pololu 6-Channel Micro Maestro — New Installation Calibration

---

## Overview

All base servo position data for the FlthyHPs system lives in **FlthyHPs_Maestro_Script.mscr**, not in the Arduino sketch. This means calibrating a new installation is done in **Maestro Control Center** — no sketch changes are needed for position tuning. Custom routines can be added later starting at subroutine `27`.

The process has three phases:
1. Configure channel settings and safety limits
2. Find and record positions for each HP
3. Update the script and reload it onto the Maestro

---

## What You Need

- Pololu Maestro Control Center (Windows or Linux via USB)
- USB cable connected to the Maestro
- The droid powered up with servos connected
- A copy of `FlthyHPs_Maestro_Script.mscr`

---

## Channel Assignments

| Channel | Name | HP | Axis |
|---|---|---|---|
| 0 | Front 1 | Front HP | Pan (left/right) |
| 1 | Front 2 | Front HP | Tilt (up/down) |
| 2 | Rear 1 | Rear HP | Pan (left/right) |
| 3 | Rear 2 | Rear HP | Tilt (up/down) |
| 4 | Top 1 | Top HP | Pan (left/right) |
| 5 | Top 2 | Top HP | Tilt (up/down) |

> Note: Which axis is "pan" vs "tilt" depends on your physical installation. The labels above assume a typical R2 HP mounting. If your axes are swapped, simply swap the channel numbers in the script.

---

## Phase 1 — Channel Configuration

Open Maestro Control Center and connect to the Maestro. Go to the **Channel Settings** tab.

### For each channel (0–5):

**Mode:** Set to `Servo`

**Min / Max pulse width:**
These are your hardware safety limits. The Maestro will clamp any command to within these values regardless of what the script sends — this prevents servos from stalling against mechanical stops.

- Start with a conservative range: **Min = 1200 µs, Max = 1800 µs**
- You will tighten these after finding your actual position values in Phase 2
- Final min/max should be set to just outside your outermost calibrated positions — roughly 50 µs of headroom on each end

**Speed:** Leave at `0` (unlimited) during calibration so sliders respond immediately. The sketch controls speed at runtime.

**Acceleration:** Leave at `0` during calibration. Again, the sketch sets this at runtime.

**Home position:** Leave unset for now. The sketch explicitly centers each HP on startup, so you do not need to rely on Maestro home positions.

Click **Apply Settings** before moving on. If you want a backup on your computer, use **File > Save settings file...**

---

## Phase 2 — Finding Positions

Go to the **Status** tab. You will see a slider for each channel.

### Work one HP at a time

For each HP, move both sliders simultaneously to find each position. The two channels in a pair work together — moving one axis affects the perceived direction of the HP, and because the axes may not be aligned with physical up/down/left/right, you will often need to adjust both channels to reach a clean position.

### Recommended order

Work through positions in this order for each HP:

1. **Center (position 0)** — Start here. Find the resting position where the HP is pointing straight forward (or straight down for the Top HP). This is your reference point for everything else. Note both channel values.

2. **Up (position 1)** — Move the HP to point clearly upward. Note both values.

3. **Down (position 2)** — Move to point clearly downward. Note both values.

4. **Left (position 3)** — Move to point clearly to the left. Note both values.

5. **Right (position 6)** — Move to point clearly to the right. Note both values.

6. **Upper-Left (position 4)** — Diagonal, roughly halfway between Up and Left. Note both values.

7. **Lower-Left (position 5)** — Diagonal, roughly halfway between Down and Left. Note both values.

8. **Upper-Right (position 7)** — Diagonal, roughly halfway between Up and Right. Note both values.

9. **Lower-Right (position 8)** — Diagonal, roughly halfway between Down and Right. Note both values.

### Tips

- **Go slow.** Move sliders gradually and watch for any resistance or binding sound from the servo. Stop before that point.
- **Check the whole envelope.** After finding all 9 positions, manually drag sliders through the full range between them to confirm no intermediate position causes binding.
- **The diagonal positions should feel natural.** If upper-left requires extreme values on one axis to look diagonal, the axis mapping may be swapped — check your wiring against the channel assignment table above.
- **Record µs values, not quarter-µs.** The Status tab displays in microseconds. The script needs quarter-microseconds (multiply by 4). It is easier to record µs now and convert when editing the script.
- **Symmetry is a good sanity check.** Left and Right should be roughly equal distance from Center on channel 0. Up and Down should be roughly equal on channel 1. If they are very asymmetric, verify the HP is mechanically centered at rest.

### After finding all positions — tighten your Min/Max limits

Go back to **Channel Settings** and update Min/Max for each channel:

- Find the lowest µs value you recorded for that channel across all 9 positions
- Set **Min** to that value minus 50 µs
- Find the highest µs value recorded
- Set **Max** to that value plus 50 µs

This gives a small buffer while ensuring the Maestro will always clamp any out-of-range command before it reaches the servo.

Click **Apply Settings**. If you want a backup on your computer, use **File > Save settings file...**

---

## Phase 3 — Update the Script

Open `FlthyHPs_Maestro_Script.mscr` in a text editor.

For each position in each HP block, update the two values with your recorded µs values **multiplied by 4**.

Example — if you recorded channel 0 = 1480 µs and channel 1 = 1390 µs for hp1_up:

```
sub hp1_up            # subroutine 1
  5920 0 servo        # ch0 = 1480us  (1480 x 4 = 5920)
  5560 1 servo        # ch1 = 1390us  (1390 x 4 = 5560)
  quit
```

The comment showing the µs value is just for your reference — update it too so it stays accurate.

Important: these position subroutines are launched from the Arduino sketch with Maestro `restartScript(subroutine)`, so each one must end with `quit`. Using `return` here causes a subroutine call stack overflow/underflow error on the Maestro.

Custom Maestro routines start at subroutine `27`. Use `M27`, `M28`, and so on from the sketch to run them. Keep the base position routines `0-26` intact, and put any reusable pose helper subroutines at the end of the file so the base table stays easy to scan.

### Subroutine reference

| Subroutine | HP | Servo 1 (Pan) | Servo 2 (Tilt) | Position |
|---|---|---|---|---|
| 0 | Front | Ch 0 — Front 1 | Ch 1 — Front 2 | center |
| 1 | Front | Ch 0 — Front 1 | Ch 1 — Front 2 | up |
| 2 | Front | Ch 0 — Front 1 | Ch 1 — Front 2 | down |
| 3 | Front | Ch 0 — Front 1 | Ch 1 — Front 2 | left |
| 4 | Front | Ch 0 — Front 1 | Ch 1 — Front 2 | upper-left |
| 5 | Front | Ch 0 — Front 1 | Ch 1 — Front 2 | lower-left |
| 6 | Front | Ch 0 — Front 1 | Ch 1 — Front 2 | right |
| 7 | Front | Ch 0 — Front 1 | Ch 1 — Front 2 | upper-right |
| 8 | Front | Ch 0 — Front 1 | Ch 1 — Front 2 | lower-right |
| 9 | Rear | Ch 2 — Rear 1 | Ch 3 — Rear 2 | center |
| 10 | Rear | Ch 2 — Rear 1 | Ch 3 — Rear 2 | up |
| 11 | Rear | Ch 2 — Rear 1 | Ch 3 — Rear 2 | down |
| 12 | Rear | Ch 2 — Rear 1 | Ch 3 — Rear 2 | left |
| 13 | Rear | Ch 2 — Rear 1 | Ch 3 — Rear 2 | upper-left |
| 14 | Rear | Ch 2 — Rear 1 | Ch 3 — Rear 2 | lower-left |
| 15 | Rear | Ch 2 — Rear 1 | Ch 3 — Rear 2 | right |
| 16 | Rear | Ch 2 — Rear 1 | Ch 3 — Rear 2 | upper-right |
| 17 | Rear | Ch 2 — Rear 1 | Ch 3 — Rear 2 | lower-right |
| 18 | Top | Ch 4 — Top 1 | Ch 5 — Top 2 | center |
| 19 | Top | Ch 4 — Top 1 | Ch 5 — Top 2 | up |
| 20 | Top | Ch 4 — Top 1 | Ch 5 — Top 2 | down |
| 21 | Top | Ch 4 — Top 1 | Ch 5 — Top 2 | left |
| 22 | Top | Ch 4 — Top 1 | Ch 5 — Top 2 | upper-left |
| 23 | Top | Ch 4 — Top 1 | Ch 5 — Top 2 | lower-left |
| 24 | Top | Ch 4 — Top 1 | Ch 5 — Top 2 | right |
| 25 | Top | Ch 4 — Top 1 | Ch 5 — Top 2 | upper-right |
| 26 | Top | Ch 4 — Top 1 | Ch 5 — Top 2 | lower-right |

---

## Phase 4 — Load the Script onto the Maestro

1. In Maestro Control Center, go to the **Script** tab
2. Paste the contents of `FlthyHPs_Maestro_Script.mscr` into the script editor
3. If you want the script to start automatically after power-up, enable **Run script on startup**
4. Click **Apply Settings**
5. Use **File > Save settings file...** to save a portable backup after the script is loaded

Important:
- Do not try to build a new script-bearing settings file by hand from `UscCmd --getconf` output
- Pololu stores the script source code on the PC and in settings files saved by **Maestro Control Center**, not on the Maestro itself
- `UscCmd --getconf` is useful for exporting device settings, but it is not a reliable starting point for hand-authoring a `<Script>` block
- Once you have a valid settings file saved from Maestro Control Center, you can use `UscCmd --configure FILE` later to load that complete settings file onto another Maestro
- If you need to re-load only the custom routine edits, remember that the sketch uses `M##` for direct Maestro subroutines and `DT...` for the normal HP commands

---

## Phase 5 — Verify

With the Arduino sketch running and the Maestro connected:

1. Power everything up — the sketch centers each HP on startup by sending the base center position. All three HPs should move to center.
2. Send a twitch command (`A104`) and watch the HPs move through random positions. Verify no binding or stalling.
3. Send a wag command (`A105` for left/right, `A106` for up/down) and verify the motion looks correct. You can append `S`, `M`, or `F` for speed, for example `A105|20S`.
4. Send preset position commands (`F101P` where P = 0–8) to individually verify each named position on the Front HP.
5. Send `M27` to verify the custom Maestro clock routine runs after the base positions are loaded.

If any position looks wrong or causes binding:
- Go back to the Status tab, find the correct values
- Update the script
- Reload via Script tab
- No sketch upload needed

---

## Adding More Positions

The script has room for additional positions well within the Maestro's script memory limit. To add a position:

1. Leave subroutines `0-26` alone unless you are changing the base position table.
2. Add new custom subroutines starting at `27` and above.
3. Keep any reusable pose helper subroutines at the end of the file so the base table stays readable.
4. If you add new base positions, increment `Config::HP_POSITIONS` in the sketch from `9` to the new total and update both the sketch and script together.

---

## Quick Reference — Conversion

| µs | Quarter-µs |
|---|---|
| 1000 | 4000 |
| 1100 | 4400 |
| 1200 | 4800 |
| 1300 | 5200 |
| 1400 | 5600 |
| 1500 | 6000 (center) |
| 1600 | 6400 |
| 1700 | 6800 |
| 1800 | 7200 |
| 1900 | 7600 |
| 2000 | 8000 |

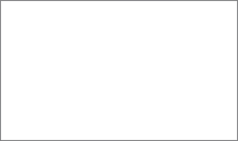
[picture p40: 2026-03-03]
docs/manual_images/image130.png

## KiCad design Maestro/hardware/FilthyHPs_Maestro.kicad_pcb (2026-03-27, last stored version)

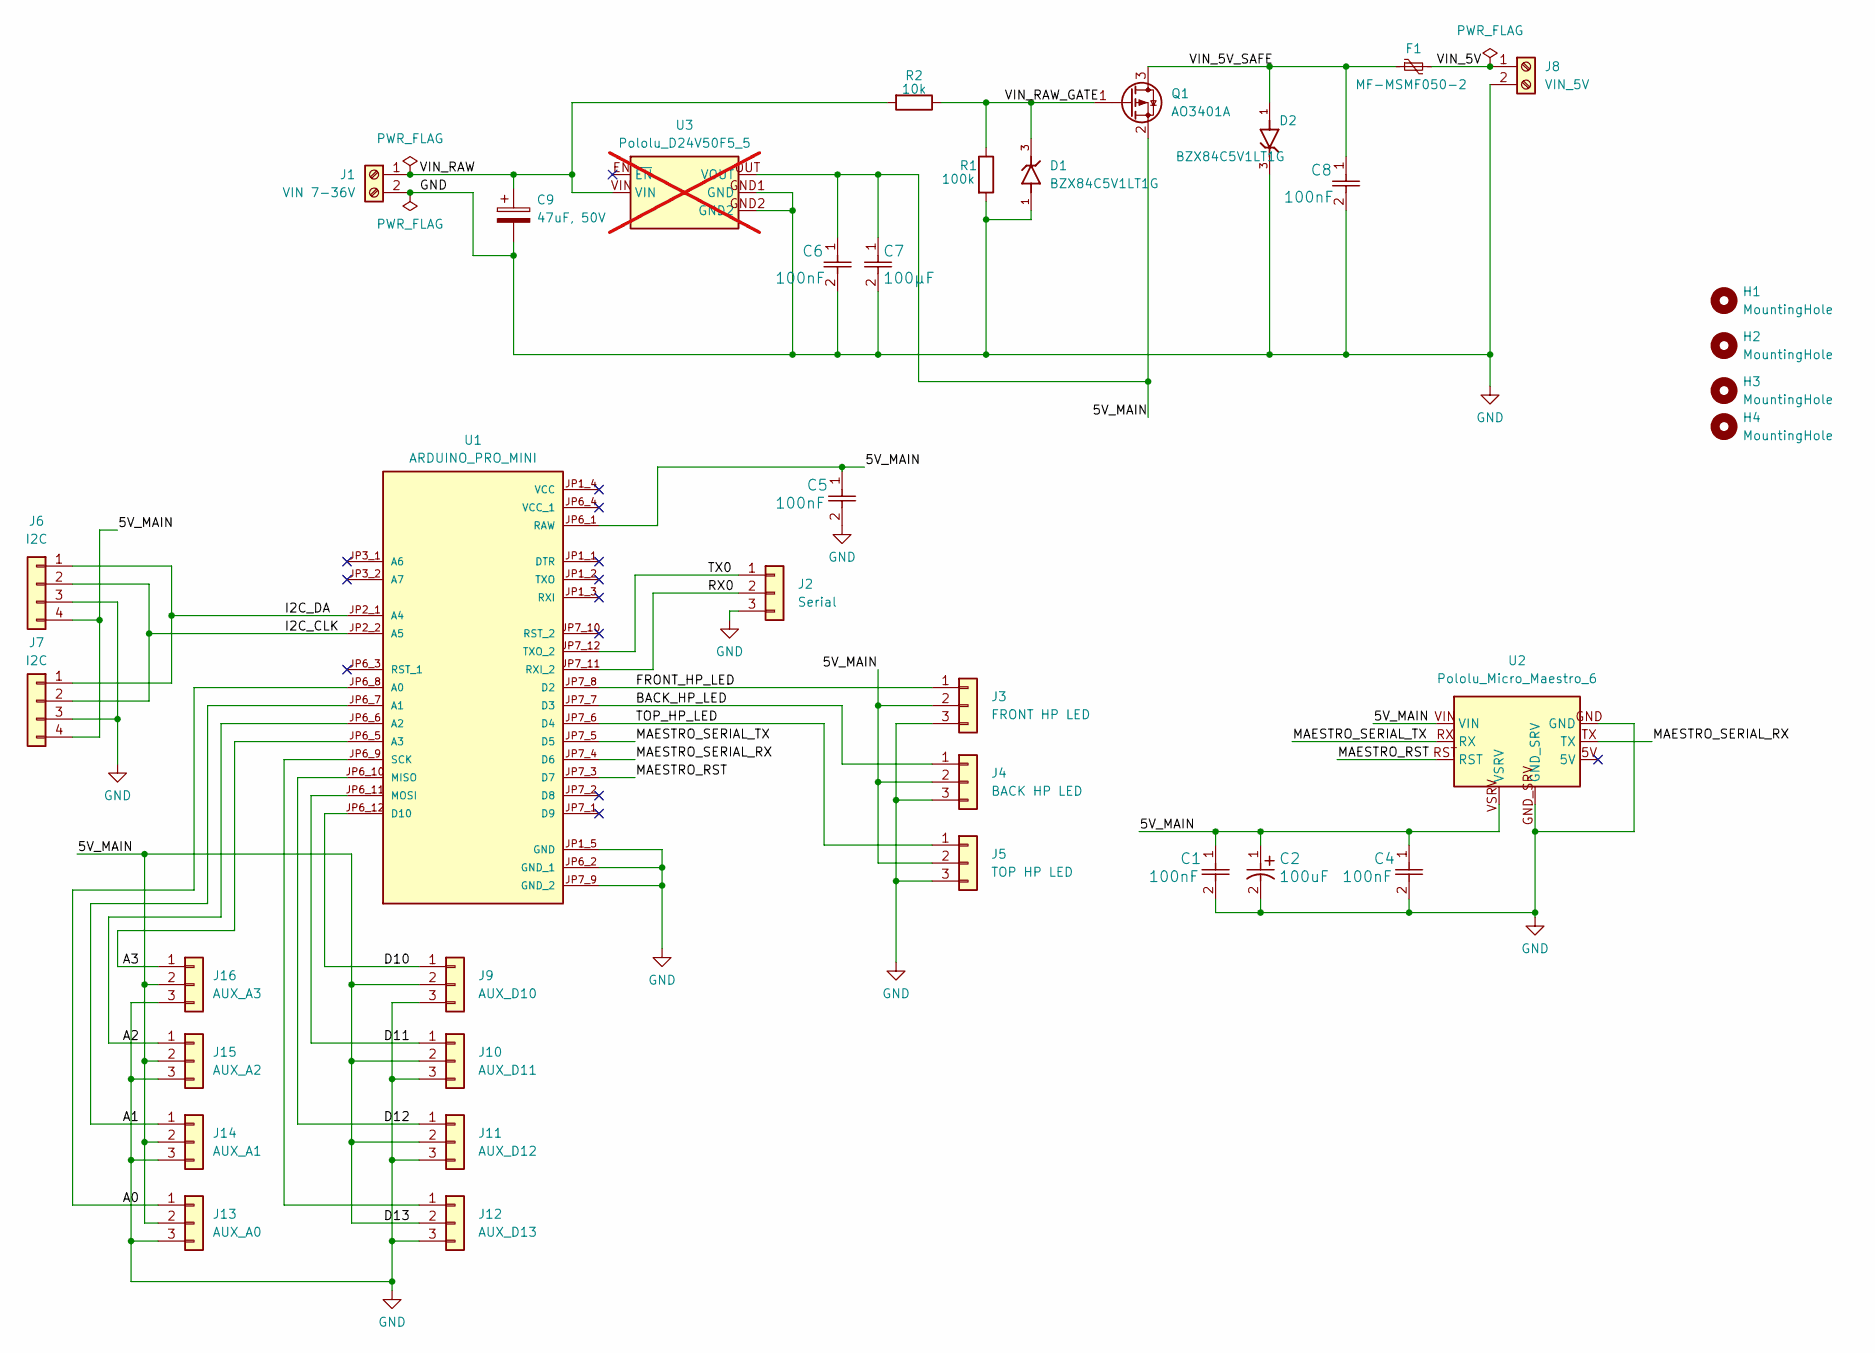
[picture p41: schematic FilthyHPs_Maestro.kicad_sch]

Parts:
C1, C4, C5, C6, C8: 100nF; G-188_MUR
C2: 100uF; CP_Elec_6.3x5.4; Part# DMBJ RVT1C101M0605; JLCPCB# C970684
C7: 100µF; C_0805_2012Metric_Pad1.18x1.45mm_HandSolder; Part# Samsung CL21A107MQYNNWE
C9: 47uF, 50V; CP_Elec_8x10; Part# Kemet A767KN476M1HLAE029
D1, D2: BZX84C5V1LT1G; SOT95P240X111-3N; PARTREV 23
F1: MF-MSMF050-2; Fuse_1812_4532Metric_Pad1.30x3.40mm_HandSolder
H1, H2, H3, H4: MountingHole; MountingHole_2.2mm_M2_DIN965_Pad_TopBottom
J1: VIN 7-36V; TerminalBlock_MaiXu_MX126-5.0-02P_1x02_P5.00mm
J2: Serial; PinHeader_1x03_P2.54mm_Vertical
J3: FRONT HP LED; PinHeader_1x03_P2.54mm_Vertical
J4: BACK HP LED; PinHeader_1x03_P2.54mm_Vertical
J5: TOP HP LED; PinHeader_1x03_P2.54mm_Vertical
J6, J7: I2C; PinHeader_1x04_P2.54mm_Vertical
J8: VIN_5V; TerminalBlock_MaiXu_MX126-5.0-02P_1x02_P5.00mm
J9: AUX_D10; PinHeader_1x03_P2.54mm_Vertical
J10: AUX_D11; PinHeader_1x03_P2.54mm_Vertical
J11: AUX_D12; PinHeader_1x03_P2.54mm_Vertical
J12: AUX_D13; PinHeader_1x03_P2.54mm_Vertical
J13: AUX_A0; PinHeader_1x03_P2.54mm_Vertical
J14: AUX_A1; PinHeader_1x03_P2.54mm_Vertical
J15: AUX_A2; PinHeader_1x03_P2.54mm_Vertical
J16: AUX_A3; PinHeader_1x03_P2.54mm_Vertical
Q1: AO3401A; SOT-23
R1: 100k; R_0805_2012Metric_Pad1.20x1.40mm_HandSolder
R2: 10k; R_0805_2012Metric_Pad1.20x1.40mm_HandSolder
U1: ARDUINO_PRO_MINI; MODULE_ARDUINO_PRO_MINI; PARTREV N/A
U2: Pololu_Micro_Maestro_6; Module_Pololu_Micro_Maestro_6_Mechanical
U3: Pololu_D24V50F5_5; Converter_DCDC_Pololu_D24V50F5; not fitted

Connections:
/5V_MAIN: C1.1, C2.1, C4.1, C5.1, C6.1, C7.1, J3.2, J4.2, J5.2, J6.4, J7.4, J9.2, J10.2, J11.2, J12.2, J13.2, J14.2, J15.2, J16.2, Q1.2 (S), U1.JP6_1 (RAW), U2.VIN, U2.VSRV, U3.OUT (VOUT)
/A0: J13.1, U1.JP6_8 (A0)
/A1: J14.1, U1.JP6_7 (A1)
/A2: J15.1, U1.JP6_6 (A2)
/A3: J16.1, U1.JP6_5 (A3)
/BACK_HP_LED: J4.1, U1.JP7_7 (D3)
/D10: J9.1, U1.JP6_12 (D10)
/D11: J10.1, U1.JP6_11 (MOSI)
/D12: J11.1, U1.JP6_10 (MISO)
/FRONT_HP_LED: J3.1, U1.JP7_8 (D2)
/I2C_CLK: J6.2, J7.2, U1.JP2_2 (A5)
/I2C_DA: J6.1, J7.1, U1.JP2_1 (A4)
/MAESTRO_RST: U1.JP7_3 (D7), U2.RST
/MAESTRO_SERIAL_RX: U1.JP7_4 (D6), U2.TX
/MAESTRO_SERIAL_TX: U1.JP7_5 (D5), U2.RX
/RX0: J2.2, U1.JP7_11 (RXI_2)
/TOP_HP_LED: J5.1, U1.JP7_6 (D4)
/TX0: J2.1, U1.JP7_12 (TXO_2)
/VIN_5V: F1.2, J8.1
/VIN_5V_SAFE: C8.1, D2.1, F1.1, Q1.3 (D)
/VIN_RAW: C9.1, J1.1, R2.2, U3.VIN
/VIN_RAW_GATE: D1.3, Q1.1 (G), R1.1, R2.1
GND: C1.2, C2.2, C4.2, C5.2, C6.2, C7.2, C8.2, C9.2, D1.1, D2.3, J1.2, J2.3, J3.3, J4.3, J5.3, J6.3, J7.3, J8.2, J9.3, J10.3, J11.3, J12.3, J13.3, J14.3, J15.3, J16.3, R1.2, U1.JP1_5 (GND), U1.JP1_6 (GND), U1.JP6_2 (GND_1), U1.JP7_9 (GND_2), U2.GND, U2.GND_SRV, U3.GND1 (GND), U3.GND2
unnamed: J12.1, U1.JP6_9 (SCK)

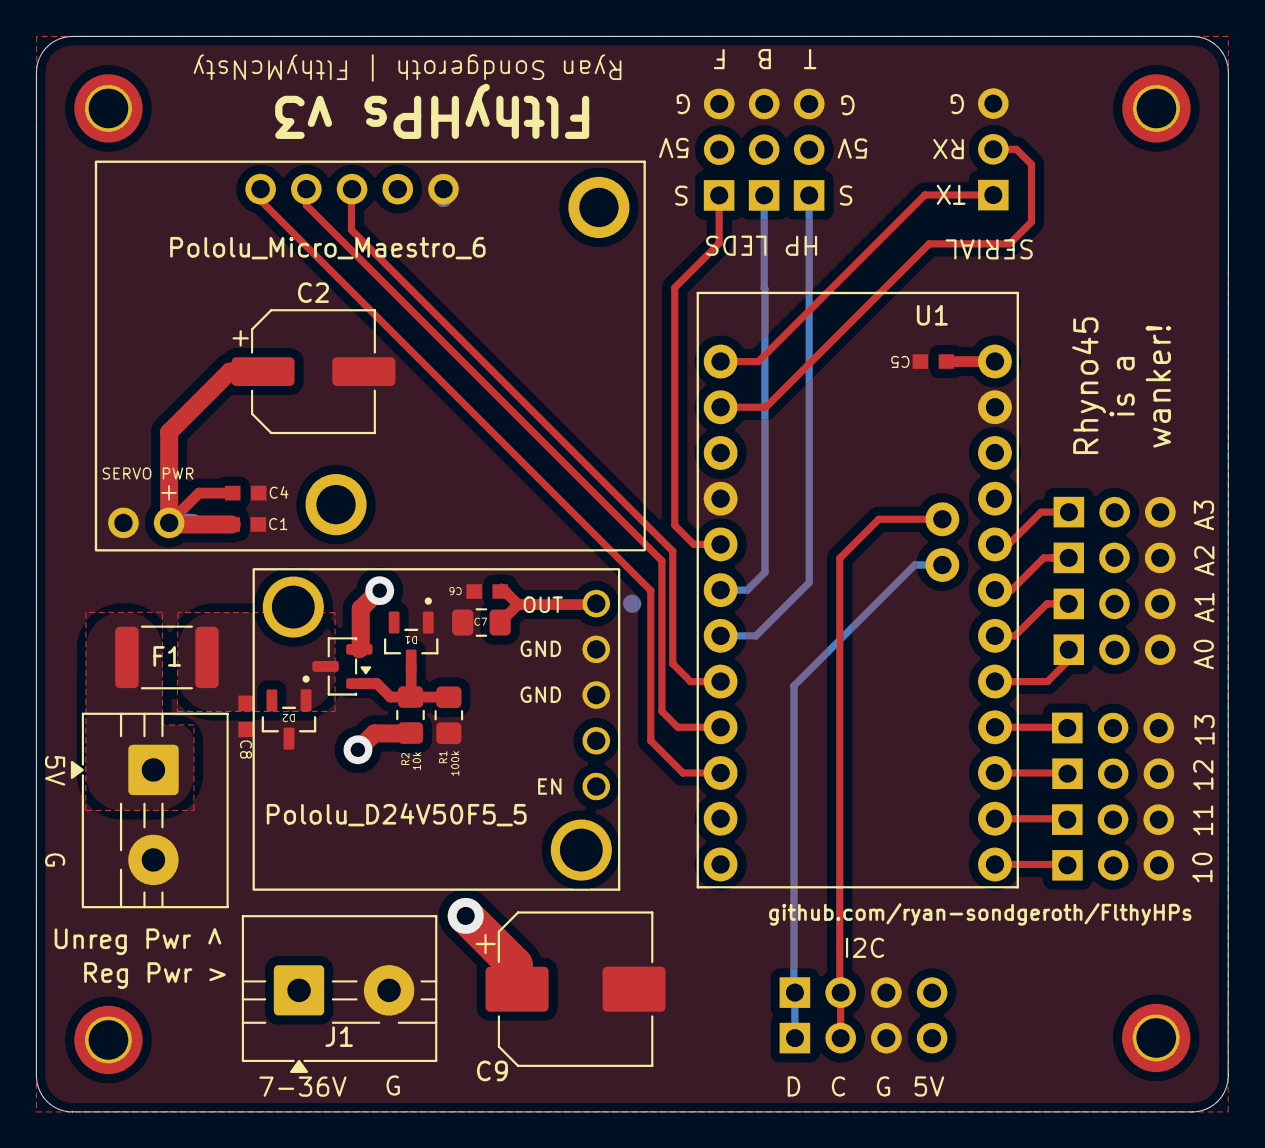
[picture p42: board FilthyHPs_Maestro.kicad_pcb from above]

Board: 2 copper layers, 66.2 x 59.8 mm, 37 parts (0 on the bottom side), 24 nets.

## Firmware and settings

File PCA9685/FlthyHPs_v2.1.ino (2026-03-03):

/////////////////////////////////////////////////////////////////////////////////////////////////////////////////
///                                                                                                           ///
///                                    Flthy Holoprojectors v2.1                                              ///
///                                       by Ryan Sondgeroth                                                  ///
///                                         aka FlthyMcNsty                                                   ///
///                                           01-23-2026                                                      ///
///                                                                                                           ///
///      Combines the movement and display functions of each Holoprojector into a single easy                 ///
///     to control sketch.  It utilizes 7 LED NeoPixel boards inside each HP to produce a more                ///
///        life-like representation of a hologram projection. Servo control is handled by a                   ///
///      Adafruit 16 Channel I2C Breakout board, giving increased flexibility over the I2C bus,               ///
///     as well as the ability to operate the HP Servos with Neopixel LEDs from the same sketch.              ///
///       The regular arduino servo library doesn't get along with Adafruits Neopixel library,                ///
///                  Big Happy Dude's Slow Servo Library is much better any way, :-D                          ///
///                                                                                                           ///
///                        Rhyno45 is a Wanker, in case Ya'll didn't know!                                    ///
///                                                                                                           ///
///                                                                                                           ///
///                                      Special thanks to...                                                 ///
///   LostRebel and Knightshade for significant input on both the general functions of the system             ///
///          and this code!  It helped me make vast improvements in operation and effeciency.                 ///
///                                                                                                           ///
///                  Huge shout out to Nobser for the major improvements in v2.0!                             ///
///                                                                                                           ///
///                                                                                                           ///
///   Version History:                                                                                        ///
///     v2.1 - Added smooth servo acceleration/deceleration (easing):                                        ///
///            - Implemented ease-in-out, ease-in, and ease-out movement curves                              ///
///            - Configurable easing duration and enable/disable toggle                                      ///
///            - Integrated seamlessly into existing movement functions                                      ///
///            - Makes all servo movements look more natural and less robotic                                ///
///     v2.0 - Refactored for major improvements in efficiency and readability:                               ///
///            - Big Ups to Nobser for this amazing refactor!                                                 ///
///            - Added duration parsing for timed commands (pipe syntax)                                      ///
///            - Added readable error messages for better debugging                                           ///
///            - Moved all magic numbers to constants                                                         ///
///            - Replaced String class with char arrays to prevent heap fragmentation                         ///
///            - Added robust command parser with error handling                                              ///
///            - Implemented timer classes for better timing management                                       ///
///            - Consolidated all constants in namespaces                                                     ///
///            - Removed duplicate code in main loop                                                          ///
///            - Added bounds checking for all array accesses                                                 ///
///            - Improved memory usage with better data structures                                            ///
///            - Added a 'help' command to display command usage in the Serial Monitor.                       ///
///            - Optimized SRAM usage by moving large color arrays to PROGMEM.                                ///
///            - Replaced floating-point math with faster integer math for a performance boost.               ///
///            - Reduced code duplication by consolidating repeated logic into new helper functions.          ///
///            - Improved readability by replacing numeric command codes with named constants.                ///
///     v1.8 - Added the ability to set custom "Off Colors" per IOIIOOO's (Jason Cross) request               ///
///     v1.7 - Bug fix identified by skelmir. Thanks, for the input, my friend.                               ///
///     v1.6 - Added random LED sequences, DEBUG feedback, compiler directives, PROGMEM usage.                ///
///     v1.5 - Updated mapPulselength function to be more accurate.                                           ///
///     v1.4 - Updated volatile variable handling.                                                            ///
///     v1.3 - Added sequence runtime via command string, added X,Y,Z designators.                            ///
///     v1.2 - Major overhaul with bug fixes, streamlined functions, more presets, new features.              ///
///     v1.1 - Added One Time HP Twitch Function                                                              ///
///                                                                                                           ///
///                                                                                                           ///
/////////////////////////////////////////////////////////////////////////////////////////////////////////////////
///                                                                                                           ///
///     Commands and Structure                                                                                ///
///                                                                                                           ///
///     DT##C or DT##CS or DT##R or DT##P                                                                     ///
///                                                                                                           ///
///     D - the HP designator                                                                                 ///
///          F - Front HP                                                                                     ///
///          R - Rear HP                                                                                      ///
///          T - Top HP                                                                                       ///
///          A - All 3 HPs                                                                                    ///
///          X - Front & Rear HPs                                                                             ///
///          Y - Front & Top HPs                                                                              ///
///          Z - Rear & Top HPs                                                                               ///
///          S - Sequences (See Below)                                                                        ///
///                                                                                                           ///
///     T - the Sequence Type is either 0-Led Fuctions and 1-Servo Functions                                  ///
///                                                                                                           ///
///    ## - the Sequence Value including leading zero if necessary, ie sequence 3 is 03                       ///
///                                                                                                           ///
///     C - (Optional), the Color integer value from list below:                                              ///
///        Basic Color Integer Values                                                                         ///
///           1 = Red                                                                                         ///
///           2 = Yellow                                                                                      ///
///           3 = Green                                                                                       ///
///           4 = Cyan (Aqua)                                                                                 ///
///           5 = Blue                                                                                        ///
///           6 = Magenta                                                                                     ///
///           7 = Orange                                                                                      ///
///           8 = Purple                                                                                      ///
///           9 = White                                                                                       ///
///           0 = Random                                                                                      ///
///                                                                                                           ///
///     S - (Optional), Speed setting integer for the Dim Pulse LED function below (0-9)                      ///
///                                                                                                           ///
///     R - (Optional), Random State for clearing LED displays                                                ///
///        Random State Integer Values                                                                        ///
///           1 = Use Default Sequences                                                                       ///
///           2 = Use Random Sequences                                                                        ///
///                                                                                                           ///
///     P - (Optional), the Position integer value from list below:                                           ///
///        Preset Position Integer Values                                                                     ///
///           0 = Down                                                                                        ///
///           1 = Center                                                                                      ///
///           2 = Up                                                                                          ///
///           3 = Left                                                                                        ///
///           4 = Upper Left                                                                                  ///
///           5 = Lower Left                                                                                  ///
///           6 = Right                                                                                       ///
///           7 = Upper Right                                                                                 ///
///           8 = Lower Right                                                                                 /// 
///                                                                                                           ///
///     D001    - Leia Sequence, Random shades of blue to mimic Leia Hologram                                 ///
///     D002C   - Color Projector Sequence, Like Leia above but using color command value                     ///
///     D003CS  - Dim Pulse Sequence, Color slowly pulses on and off                                          ///
///     D004C   - Cycle Sequence, using color command value                                                   ///
///     D005C   - Toggles Color, Simply sets LEDs tp solid color value.                                       ///
///     D006    - Rainbow Sequence                                                                            ///
///     D007C   - Short Circuit, Led flashes on and off with interval slowing over time                       ///
///     D096    - Clears LED, Disables Auto LED Sequence & "Off Color"                                        ///
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
void loop() {
   // Move servos
   Servos::move(millis());

   // Update servo easing for all HPs
   if (Config::ENABLE_SERVO_EASING) {
       for (uint8_t i = 0; i < Config::HP_COUNT; i++) {
           updateServoEasing(i);
       }
   }

   // Check status LED
   if (statusLedTimer.check()) {
       digitalWrite(STATUS_LED_PIN, LOW);
   }
   
   // Process complete command
   if (stringComplete) {
       Command cmd = parseCommand(commandBuffer.get());
       
       if (cmd.device == 'H' && strcasecmp(commandBuffer.get(), "help") == 0) {
           printHelp();
       } else {
           CommandError error = validateCommand(cmd);
           if (error == CommandError::OK) {
               processCommand(cmd);
               #ifdef DEBUG
               Serial.print(F("Command processed: "));
               Serial.println(commandBuffer.get());
               #endif
           } else {
               Serial.print(F("Error: "));
               Serial.println(errorToString(error));
           }
       }
       
       commandBuffer.clear();
       stringComplete = false;
   }
   
   // Process LED commands
   for (uint8_t i = 0; i < Config::HP_COUNT; i++) {
       // Check halt time
       if (ledCommands[i].halt > 0 && (millis() - ledHaltTime[i] >= ledCommands[i].halt * 1000UL)) {
           flushCommandArray(i, 0);
           ledOff(i);
           resetLEDTwitch(i);
       }
       
       // Execute LED function
       switch (ledCommands[i].function) {
           case LedFunction::LEIA:
               colorProjector(i, 5);
               break;
           case LedFunction::COLOR_PROJECTOR:
               colorProjector(i, ledCommands[i].option1);
               break;
           case LedFunction::DIM_PULSE:
               dimPulse(i, ledCommands[i].option1, ledCommands[i].option2);
               break;
           case LedFunction::CYCLE:
               cycle(i, ledCommands[i].option1);
               break;
           case LedFunction::SOLID_COLOR:
           case LedFunction::SET_OFF_COLOR:
               ledColor(i, ledCommands[i].option1);
               break;
           case LedFunction::RAINBOW:
               rainbow(i);
               break;
           case LedFunction::SHORT_CIRCUIT:
               shortCircuit(i, ledCommands[i].option1);
               break;
           case LedFunction::CLEAR_NO_AUTO_OVERRIDE_ON:
               enableTwitchLED[i] = 0;
               resetLEDTwitch(i);
               offColorOverride[i] = true;
               flushCommandArray(i, 0);
               break;
           case LedFunction::CLEAR_AUTO_OVERRIDE_ON:
               enableTwitchLED[i] = (ledCommands[i].option1 == 1 || ledCommands[i].option1 == 2) ? 
                                    ledCommands[i].option1 : startEnableTwitchLED[i];
               resetLEDTwitch(i);
               offColorOverride[i] = true;
               flushCommandArray(i, 0);
               break;
           case LedFunction::CLEAR_NO_AUTO_OVERRIDE_OFF:
               enableTwitchLED[i] = 0;
               resetLEDTwitch(i);
               offColorOverride[i] = false;
               flushCommandArray(i, 0);
               break;
           case LedFunction::CLEAR_AUTO_OVERRIDE_OFF:
               enableTwitchLED[i] = (ledCommands[i].option1 == 1 || ledCommands[i].option1 == 2) ? 
                                    ledCommands[i].option1 : startEnableTwitchLED[i];
               resetLEDTwitch(i);
               offColorOverride[i] = false;
               flushCommandArray(i, 0);
               break;
           default:
               break;
       }
       
       // Auto LED twitch
       if (enableTwitchLED[i] > 0 && ledTwitchTimers[i].check() && 
           (uint8_t)ledCommands[i].function > (uint8_t)LedFunction::SHORT_CIRCUIT) {
           
           twitchLEDRunTime[i] = random(readLedTwitchRunInterval(i, 0), readLedTwitchRunInterval(i, 1));
           ledHaltTime[i] = millis();
           resetAnimation(i);
           
           if (enableTwitchLED[i] == 2) {  // Random
               ledCommands[i].function = (LedFunction)random(2, 8);
               ledCommands[i].option1 = random(0, 10);
               ledCommands[i].option2 = random(0, 10);
           } else {  // Default
               ledCommands[i].function = (LedFunction)readDefaultLedTwitchCmd(i, 0);
               ledCommands[i].option1 = readDefaultLedTwitchCmd(i, 1);
               ledCommands[i].option2 = readDefaultLedTwitchCmd(i, 2);
           }
           ledCommands[i].halt = twitchLEDRunTime[i];
           
           #ifdef DEBUG
           Serial.print(F("Auto LED Twitch: "));
           printHpName(i);
           Serial.print(F(" Function="));
           Serial.print((uint8_t)ledCommands[i].function);
           Serial.print(F(" Duration="));
           Serial.println(twitchLEDRunTime[i]);
           #endif
           
           ledTwitchTimers[i].setInterval(random(readLedTwitchInterval(i, 0), readLedTwitchInterval(i, 1)) * 1000UL);
       }
   }
   
   // Process HP commands
   for (uint8_t i = 0; i < Config::HP_COUNT; i++) {
       // Check halt time
       if (hpCommands[i].halt > 0 && (millis() - hpHaltTime[i] >= hpCommands[i].halt * 1000UL)) {
           flushCommandArray(i, 1);
           wagCount[i] = -1;
       }
       
       // Execute HP function
       switch (hpCommands[i].function) {
           case HpFunction::GOTO_PRESET:
               positionHP(i, hpCommands[i].option1, readServoSpeed(0));
               flushCommandArray(i, 1);
               break;
           #ifdef ENABLERC
           case HpFunction::RC_LEFT_RIGHT:
               rcControl(i, 1);
               break;
           case HpFunction::RC_UP_DOWN:
               rcControl(i, 2);
               break;
           #endif
           case HpFunction::RANDOM_POS:
               twitchHP(i);
               flushCommandArray(i, 1);
               break;
           case HpFunction::WAG_LEFT_RIGHT:
               wagHP(i, 1);
               break;
           case HpFunction::WAG_UP_DOWN:
               wagHP(i, 2);
               break;
           case HpFunction::AUTO_TWITCH_OFF:
               enableTwitchHP[i] = false;
               flushCommandArray(i, 1);
               break;
           case HpFunction::AUTO_TWITCH_ON:
               enableTwitchHP[i] = true;
               flushCommandArray(i, 1);
               break;
           default:
               break;
       }
       
       // Auto HP twitch
       if (enableTwitchHP[i] && hpTwitchTimers[i].check() && 
           (uint8_t)hpCommands[i].function > (uint8_t)HpFunction::WAG_UP_DOWN) {
           twitchHP(i);
           resetHPTwitch(i);
           
           #ifdef DEBUG
           Serial.print(F("Auto HP Twitch: "));
           printHpName(i);
           Serial.println();
           #endif
       }
   }
   
   // Disable servos after movement
   if (outputEnableTimer.check() && digitalRead(OUTPUT_ENABLED_PIN) == LOW) {
       digitalWrite(OUTPUT_ENABLED_PIN, HIGH);
   }
}

////////////////////////////////////////////////////////////////////////////////////////////////////////
///                                  Command Processing Functions                                      ///
////////////////////////////////////////////////////////////////////////////////////////////////////////

Command parseCommand(const char* cmdStr) {
   Command cmd;
   
   if (!cmdStr || strlen(cmdStr) < 2) {
       return cmd;
   }
   
   // Create a mutable copy for parsing
   char buffer[Config::INPUT_BUFFER_LEN];
   strncpy(buffer, cmdStr, Config::INPUT_BUFFER_LEN - 1);
   buffer[Config::INPUT_BUFFER_LEN - 1] = '\0';
   
   // Check for pipe character (duration)
   char* pipePos = strchr(buffer, '|');
   if (pipePos) {
       *pipePos = '\0';  // Split the string
       cmd.duration = atoi(pipePos + 1);
   }
   
   // Handle help
   if (strcasecmp(buffer, "help") == 0 || strcmp(buffer, "?") == 0) {
       cmd.device = 'H';
       return cmd;
   }
   
   // Parse device
   cmd.device = toupper(buffer[0]);
   
   // Parse type
   if (strlen(buffer) > 1) {
       cmd.type = buffer[1] - '0';
   }
   
   // Parse function
   if (strlen(buffer) > 3) {
       cmd.function = (buffer[2] - '0') * 10 + (buffer[3] - '0');
   }
   
   // Parse options
   if (strlen(buffer) > 4) {
       cmd.option1 = buffer[4] - '0';
   }
   
   if (strlen(buffer) > 5) {
       cmd.option2 = buffer[5] - '0';
   }
   
   return cmd;
}
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

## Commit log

2026-03-03 Add README.md for FlthyHPs project detailing features, hardware requirements, wiring, installation, configuration, and command reference
2026-03-26 Update repo to include sketch that supports Pololu Maestro servo control.
2026-03-27 Add hardware files and fabrication data for FilthyHPs Maestro project
    [10Pin_Header_Female_2p54mm.step, 10Pin_Header_Female_Double_2p54mm.step, 10Pin_Header_Male_2p54mm.step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]
2026-03-27 Update README.md with additional power input options and component details
2026-03-27 Update README.md to clarify the purpose of the Serial header for Arduino sketch commands
2026-03-27 Enhance README.md with detailed power input options and improved circuit protection and stability descriptions
2026-03-27 Update README.md to clarify I2C headers functionality and improve power stability descriptions
2026-03-27 Update README.md to simplify servo setup description and clarify I2C header usage
2026-03-27 Update .gitignore to include board design files and related artifacts
2026-03-27 Remove obsolete hardware files and fabrication artifacts from the repository
    [10Pin_Header_Female_2p54mm.step, 10Pin_Header_Female_Double_2p54mm.step, 10Pin_Header_Male_2p54mm.step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]
2026-03-27 Remove outdated references to KiCad project and fabrication files in README.md
